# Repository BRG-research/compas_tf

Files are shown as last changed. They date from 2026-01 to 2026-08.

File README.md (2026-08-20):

# compas_tf

Timber floor development. A parametric model of a timber floor — columns, ribs,
beds, t-sections, oculus and the connectors that hold them together — that you
can build, cut, measure, extract from and hand to a shop as STEP.

**Documentation: <https://brg-research.github.io/compas_tf/>**

## Use it

```bash
pip install compas_tf
```

```python
import compas

model = compas.json_load("cantilevers_baked_model.json")

print(len(list(model.geometry_elements())))   # 237
print(len(list(model.contacts())))            # 733
```

A written model is *baked* — every boolean already evaluated and stored on the
element — so it loads in 0.60 s with no boolean backend involved.
[`compas_tf_example`](https://github.com/BRG-research/compas_tf_example) is a
standalone project that does nothing but read one.

## Develop it

Needs [git](https://git-scm.com/downloads),
[uv](https://docs.astral.sh/uv/getting-started/installation/) and Python 3.10+.

```bash
git clone https://github.com/BRG-research/compas_tf.git
cd compas_tf
uv venv .venv --python 3.12
source .venv/Scripts/activate      # macOS / Linux: source .venv/bin/activate
uv pip install -r requirements.txt -r requirements-dev.txt -r requirements-viewer.txt
uv pip install -e .
```

> `uv pip`, not plain `pip` — a `uv venv` has no pip of its own, so a bare
> `pip install` lands in the wrong environment.

```bash
invoke lint
invoke test
python tools/run_examples.py     # all 21 examples, viewer suppressed
```

## Work on another branch

A fresh clone gives you `main` and nothing else — the other branches exist on
GitHub but are not yet on your machine. `git fetch` downloads them; `git switch`
gives you a local branch that tracks one.

```bash
git fetch origin --prune         # download every branch GitHub has, drop stale ones
git branch -r                    # list what is on origin
git switch quantities            # create local `quantities` tracking origin/quantities
```

`git switch <name>` with no other flags is enough when exactly one remote has a
branch of that name — git creates the local branch and sets it to track. Spell
it out when you want a different local name, or when the shorthand fails:

```bash
git switch -c quantities --track origin/quantities
```

From then on it is an ordinary branch: `git pull` to update it, `git push` to
publish, `git switch main` to go back. `git branch -vv` shows every local branch
and which remote branch it tracks.

Two things to know before switching:

- **Commit or stash first.** `git switch` refuses to move if uncommitted changes
  would be overwritten. `git status` tells you.
- **`data/` is regenerated, not shared.** The example outputs are gitignored, so
  switching branches leaves stale JSON behind and the file dates will not match
  the branch. Re-run `python tools/run_examples.py` after switching.

The environment is per-clone, not per-branch: `.venv` and the editable install
survive a `git switch`. Redo the `uv pip install` steps only when a branch
changes `requirements*.txt` or `pyproject.toml`.

## Examples

`examples/` is a chain: each reads the JSON the one before it wrote.
`example_model_18_write_model_and_brep.py` is the hinge — it bakes the model,
finds every contact, and writes the four files the readers open:

| Example | Does |
| --- | --- |
| `example_model_19_read_model.py` | the model back — elements, tree, contacts |
| `example_model_20_read_brep.py` | the STEP — 237 closed solids |
| `example_model_21_extract_bay.py` | one column + one cantilever as its own model |
| `example_model_22_read_brep_adjacency.py` | what touches what, from STEP + sidecar |

## References

- [compas_nest](https://github.com/petrasvestartas/compas_nest) — 2D nesting of part outlines.

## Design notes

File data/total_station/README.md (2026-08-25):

# Total station 3D model

`total_station_es105` — Topcon-style ES-105 total station mounted on a survey tripod.

| file | notes |
|---|---|
| `total_station_es105.obj` | Z-up, metres, origin at the instrument's vertical axis on the ground plane. Load with `Mesh.from_obj(...)`. |
| `total_station_es105.glb` | original download (glTF binary, Y-up, textured) |
| `total_station_es105_preview.jpg` | thumbnail |

- Overall size: 1.59 × 1.55 m tripod footprint, 1.73 m to the top of the instrument.
- Triangles: 25 739 (welds to 19 164 faces when read as a COMPAS `Mesh`).

## Source / attribution

- "TOTAL STATION ES 105" by *dicki A.*, Trimble 3D Warehouse (2023-02-06)
- https://3dwarehouse.sketchup.com/model/5f67aafc-05d2-4c37-b238-7d4f63390c5f
- Covered by the Trimble 3D Warehouse General Model License: free to use in your own
  projects and renderings; do not resell or redistribute the model on its own.

The `.obj` was produced from the `.glb` by a stdlib glTF reader (node transforms baked,
Y-up rotated to Z-up); no geometry was otherwise modified apart from the origin shift.

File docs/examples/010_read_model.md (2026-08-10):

# Read the model

`compas.json_load` gives back the whole thing: elements, features, materials,
the tree, and the graph with the contacts on it.

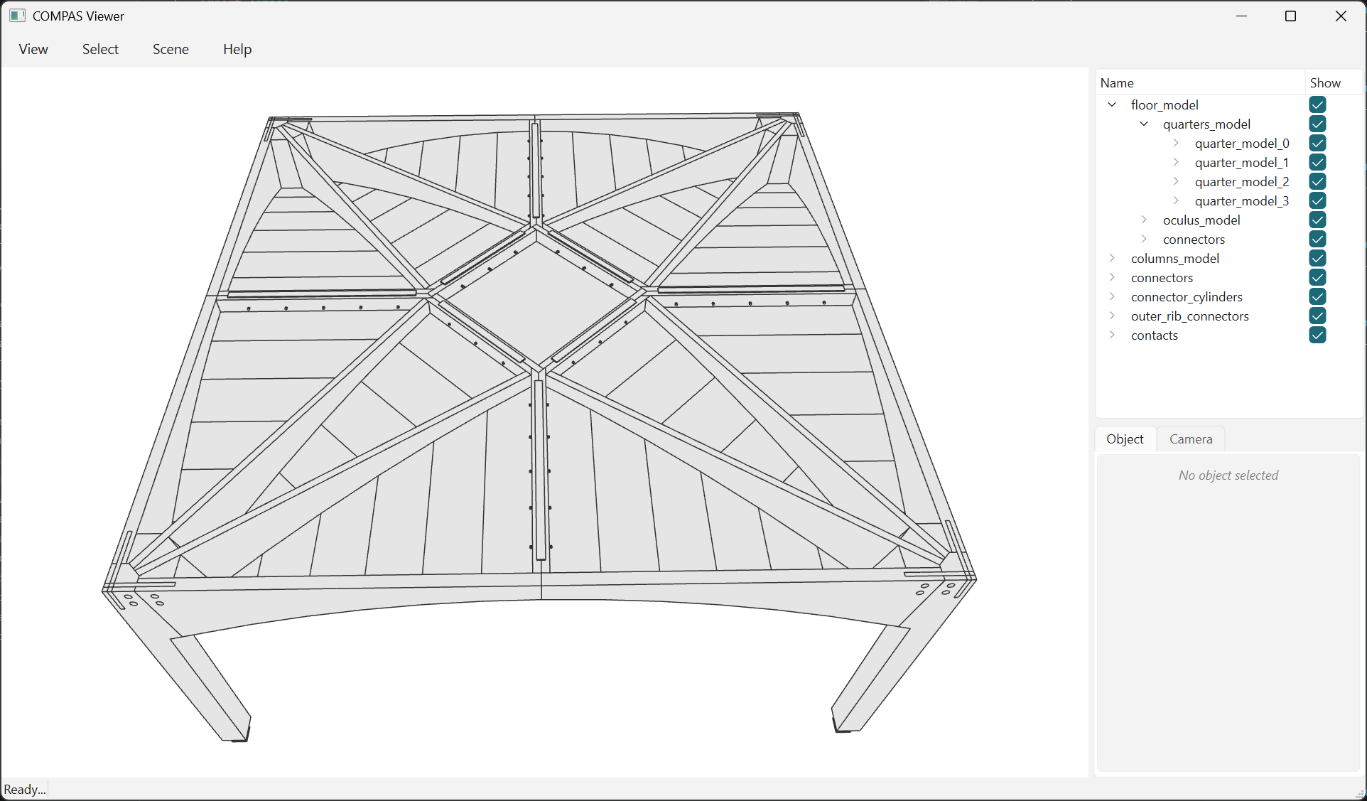
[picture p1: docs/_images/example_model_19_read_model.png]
The model loaded from JSON, with its group tree in the viewer

/// caption
237 elements, 733 contacts. The scene tree on the right is the model's own tree,
mirrored, so every group can be switched off on its own.
///

```python
--8<-- "examples/example_model_19_read_model.py"
```

```text
237 elements, 733 contacts
```

The geometry is **baked** - every boolean already evaluated and stored - so this
runs none and needs no boolean backend: 0.60 s for 3.9 MB.

What the 237 are:

```text
floor_model              185    quarters_model 136 = 4 x 34
                                oculus_model     9
                                connectors      40
columns_model              8    4 x (column + support)
connectors                 8
connector_cylinders       32
outer_rib_connectors       4
```

A quarter is 34: 18 beds, 6 t-sections, 2 outer ribs, 2 inner ribs, 3 inner
beams, 3 wedges. 145 of the 237 are `PlateElement`; the rest are the columns,
their supports, and the fasteners.

`model.elements()` yields the groups too, `geometry_elements()` only the leaves.
`model.contacts()` reads what the search stored rather than searching again.

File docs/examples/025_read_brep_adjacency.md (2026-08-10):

# Read the Breps with their adjacency

The page before draws the STEP files. This one asks them what is connected to
what, which needs the third file: the JSON sidecar.

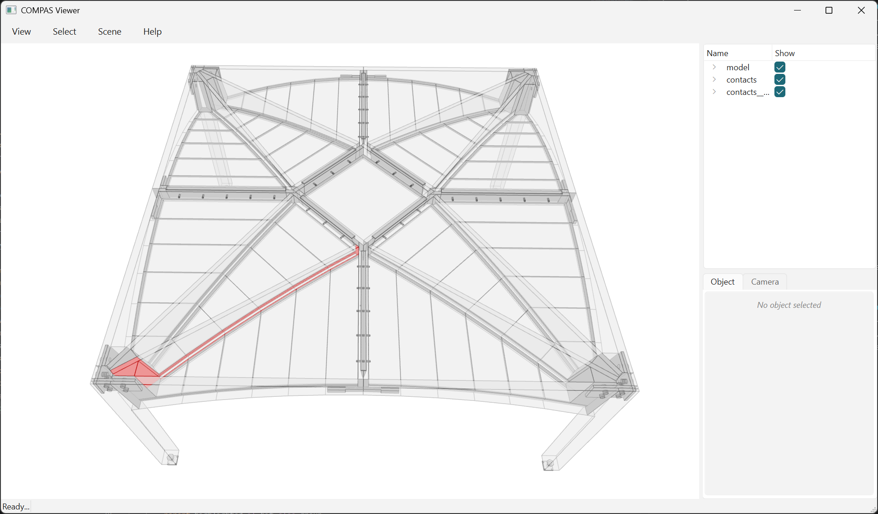
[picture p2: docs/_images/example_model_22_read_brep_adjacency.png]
One element's joints highlighted in red across the ghosted building

/// caption
The 17 contacts on `inner_ribs_0_0` in red, the rest ghosted behind them. The
sidecar is what turns "face 412" into "this rib meets that bed".
///

```python
--8<-- "examples/example_model_22_read_brep_adjacency.py"
```

```text
237 solids, 733 contact faces, 733 adjacency records
169 elements over 585 pairs, 20.92 m2 of interface

biggest joints:
   0.344 m2  inner_beams_0_1 - connector_wedge_3  (3 faces)
   0.344 m2  inner_beams_2_2 - connector_wedge_3  (3 faces)
   0.344 m2  inner_beams_0_0 - connector_wedge_0  (3 faces)
   0.344 m2  inner_beams_2_1 - connector_wedge_0  (3 faces)
   0.344 m2  inner_beams_0_2 - connector_wedge_5  (3 faces)

by type:
  12.818 m2  PlateElement - PlateElement
   4.459 m2  ConnectorWedgeElement - PlateElement
   1.106 m2  ColumnElement - PlateElement
   1.101 m2  ConnectorElement - PlateElement
   0.895 m2  ColumnElement - ConnectorElement
   0.541 m2  OuterRibConnectorElement - PlateElement

17 contacts on inner_ribs_0_0, the most connected element
```

A record per face, in the same order the faces were written:

```python
{"index": 0, "a": "beds_0_0_0", "b": "wedges_inner_beams_0_0",
 "a_type": "PlateElement", "b_type": "PlateElement",
 "a_guid": "c46c8acc-...", "b_guid": "3098146e-...",
 "area": 39851.67}
```

Three things worth knowing:

**Index is the only join.** Equal counts is the one check that the two files
came from the same run - pair a STEP with the wrong sidecar and every name lands
on the wrong face, silently.

**The names are element names.** The solids stay anonymous; nothing here says
which of the 237 is `beds_0_0_0`. For that, read the JSON model.

**A pair is not a face.** 585 pairs carry 733 faces, so group by `(a, b)` before
ranking or one joint split in three sorts below a single big one.

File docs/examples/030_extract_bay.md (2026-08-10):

# Extract one column and one cantilever

Any named group can be lifted out as a model of its own. One column plus the
cantilever it carries is the unit that gets assembled on site.

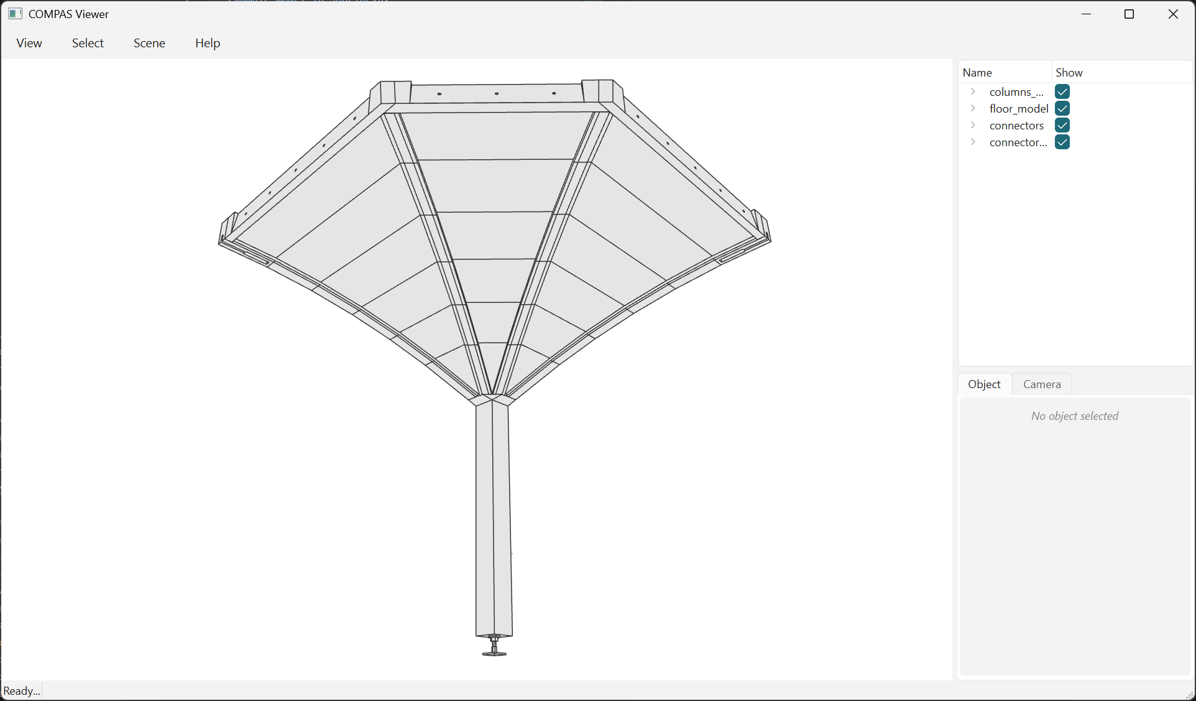
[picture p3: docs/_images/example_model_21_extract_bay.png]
One bay lifted out of the building: a column carrying one quarter

/// caption
The 46 elements that make a bay, and nothing else - cut off along the seams
where the next quarters would begin.
///

```python
--8<-- "examples/example_model_21_extract_bay.py"
```

```text
bay_0: 46 of 237 elements, 143 of 733 contacts
    34 of  145  PlateElement
     8 of   32  DowelCylinderElement
     2 of    8  ConnectorElement
     1 of    4  SupportElement
     1 of    4  ColumnElement
columns_model  (2 parts)
  column_model_0  (2 parts)
floor_model  (34 parts)
  quarters_model  (34 parts)
    quarter_model_0  (34 parts)
      beds_0  (18 parts)
        beds_0_0  (6 parts)
        beds_1_0  (6 parts)
        beds_2_0  (6 parts)
      tsections_0  (6 parts)
      outer_ribs_0  (2 parts)
      inner_ribs_0  (2 parts)
      wedges_inner_beams_0  (3 parts)
      inner_beams_0  (3 parts)
connectors  (2 parts)
connector_cylinders  (8 parts)
```

Every group keeps its place, so the bay is the same tree pruned to what it
contains, not a bag of parts. The copy is independent - fresh guids - and writes
to JSON or STEP like any other model.

**Both groups in one call.** The contacts *between* the column and its
cantilever survive only if the two come out together; extracting each on its own
and merging drops exactly that joint.

**`neighbors=` takes types, not `True`.** The fasteners live in top-level groups
holding all four bays' hardware, so they cannot be named - `neighbors=` finds
this bay's own, by contact for the connectors and by bounding box for the dowels,
which the contact search skipped and which therefore have no graph edge.

```text
neighbors=False        36 elements, 125 contacts
neighbors=FASTENERS    46 elements, 143 contacts
neighbors=True         77 elements, 208 contacts
```

`True` admits anything that touches: four plates from the quarters next door,
two oculus plates, and then `connector_wedge_7`'s cylinders, whose boxes overlap
one of those oculus plates. Naming the types stops that at the first step.

The groups you can name:

```text
floor_model                    185 parts
  quarters_model               136
    quarter_model_0 .. _3       34 each
      beds_0, tsections_0, outer_ribs_0, inner_ribs_0,
      wedges_inner_beams_0, inner_beams_0
  oculus_model                   9
  connectors                    40
columns_model                    8
  column_model_0 .. _3           2 each
connectors                       8
connector_cylinders             32
outer_rib_connectors             4
```

A name that matches nothing raises `ModelElementNotFound`.

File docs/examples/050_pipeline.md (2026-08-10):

# The full pipeline

The other pages read a finished model. This is where it comes from: a chain of
examples, each reading the JSON the one before it wrote.

```bash
python tools/run_examples.py            # all of them
python tools/run_examples.py 8 9 10     # only those, by number
```

The runner suppresses the viewer window but still builds the scene, so broken
geometry still raises, and it rewrites everything in `data/`.

| Example | Reads | Writes |
| --- | --- | --- |
| `1_floorguide` | the parameters | `floorguide.json` |
| `2_column_model` | `floorguide` | `column_model.json` |
| `3_columns_model` | `floorguide`, `column_model` | `columns_model.json` |
| `4_quarters` | `floorguide` | `quarter_model`, `quarters_model` |
| `5_oculus` | `floorguide` | `oculus_model.json` |
| `6_contacts_floor` | `quarters_model`, `oculus_model` | `floor_model.json` |
| `7_contacts_cantilever` | `quarter_model`, `column_model` | `cantilever_model.json` |
| `8_contacts_cantilevers` | `floor_model`, `columns_model` | `cantilevers_model.json` |
| `9_wedge_connector` | - | the wedge connector on its own |
| `10_shoring` | `floorguide` | `shoring_model.json` |
| `11_full` | `cantilever_model`, `shoring_model` | `full_model.json` |
| `12`, `13`, `14`, `16` | `cantilevers_model` | the parts laid out flat for fabrication |

Step 8 is the whole building: 237 elements, four quarters on four columns,
everything cut and bolted.

`18_write_model_and_brep` is the hinge. It bakes that model - every boolean
evaluated once and stored - searches every element pair for contacts on the Brep
faces, and writes the four files the reading pages open:

```text
cantilevers_baked_model.json      3.9 MB
cantilevers_baked_model.stp      19.5 MB
cantilevers_baked_contacts.stp    4.7 MB
cantilevers_baked_contacts.json   201 KB
```

It is the only step that runs a boolean, and the only one that needs a boolean
backend. Everything downstream just opens files.

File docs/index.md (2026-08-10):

# compas_tf

`compas_tf` builds the timber floor as a parametric model - columns, ribs, beds,
t-sections, the oculus and the connectors - every element boolean-cut and
contact-checked. The finished model is written as JSON and as STEP.

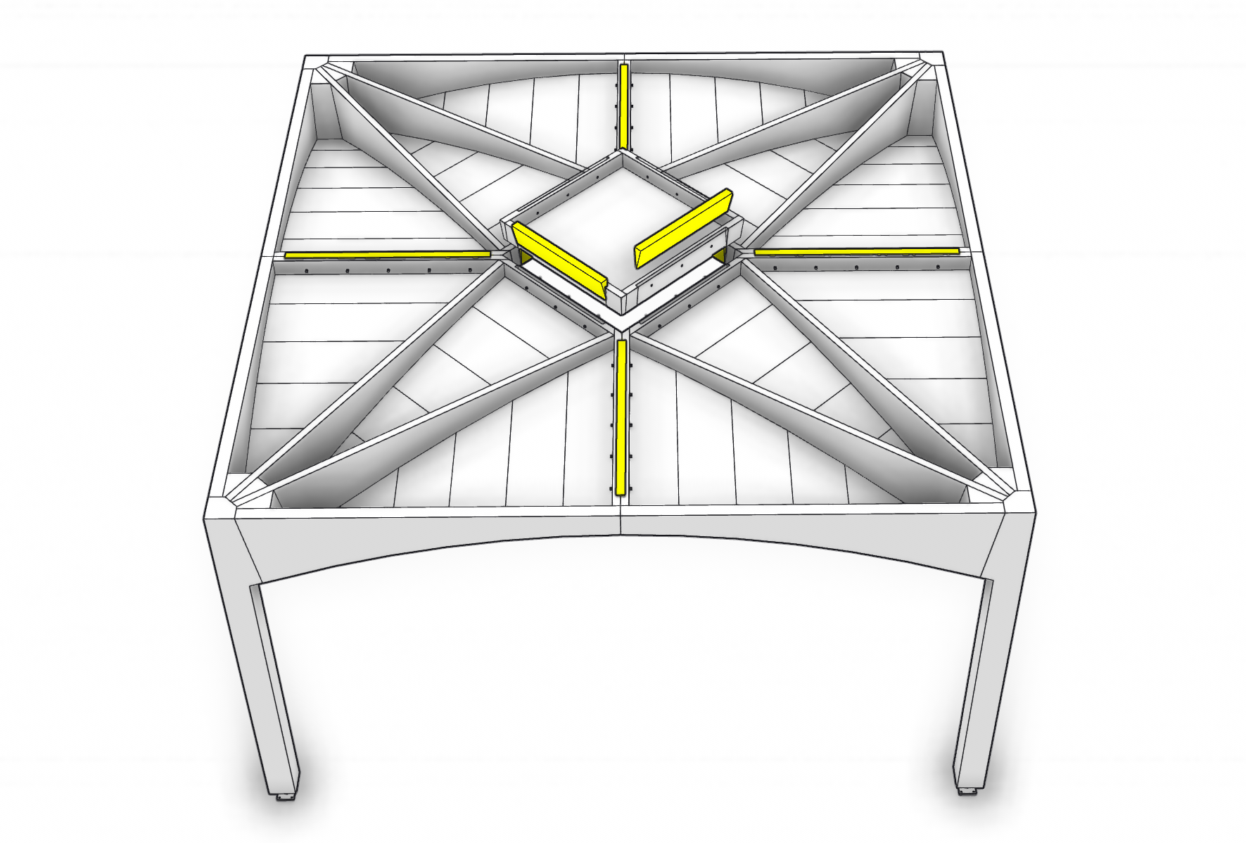
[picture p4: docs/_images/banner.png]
One bay of the timber floor

/// caption
One bay: four quarters of ribs, beds and t-sections on a column, an oculus at
the centre, and the connectors in yellow.
///

[**The presentation**](https://docs.google.com/presentation/d/1b6M9fYuQjmKMM1xWZPiqj3Y3arJCszfi/edit?slide=id.p1#slide=id.p1)
- the whole project.

[**The model as STEP**](https://github.com/BRG-research/compas_tf/raw/main/data/cantilevers_baked_model.stp)
- when geometry preview is only needed. Also as
[JSON](https://github.com/BRG-research/compas_tf/raw/main/data/cantilevers_baked_model.json),
which keeps the names, the tree and the contacts.

Reading a finished model needs nothing but `compas_tf` - start with the
[examples](examples/010_read_model.md).

Built on [compas](https://compas.dev),
[compas_model](https://github.com/blockresearchgroup/compas_model),
[compas_occt](https://github.com/petrasvestartas/compas_occt),
[compas_manifold](https://github.com/petrasvestartas/compas_manifold) and
[shapely](https://shapely.readthedocs.io), with
[compas_viewer](https://github.com/compas-dev/compas_viewer) for the pictures.

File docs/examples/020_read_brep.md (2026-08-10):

# Read the Breps

The STEP file is the same geometry with no compas_tf concepts in it: solids, the
way a shop gets them.

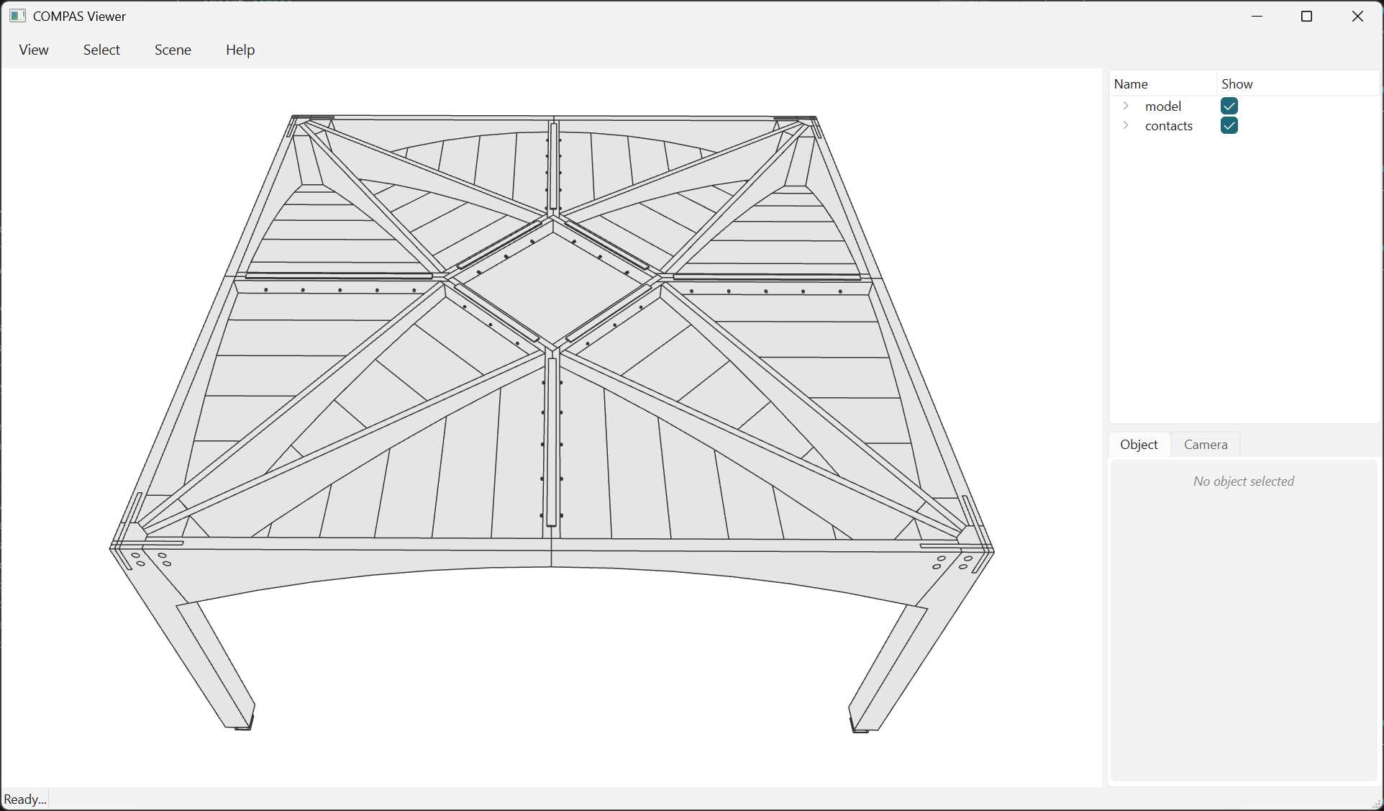
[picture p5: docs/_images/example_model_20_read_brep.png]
The same building read back from STEP

/// caption
237 solids, 19.5 MB, no compas_tf needed to open it. Compare the scene tree with
the page before: two flat entries. STEP carries no names and no hierarchy, so
there is nothing to mirror.
///

```python
--8<-- "examples/example_model_20_read_brep.py"
```

```text
237 solids, 4779 faces, 733 contacts
```

The model is one compound, so `.solids` splits out the parts. The contacts are a
second file: they are loose faces, which `.solids` would drop. Coplanar faces
were merged before writing, so 13730 mesh faces come back as 4779 Brep faces,
each drilled face carrying its hole loops.

**Set the deflection.** At the `0.001` default the building tessellates to 2.93M
triangles in 67 s; at `1.0` it is 19.8k in 2.0 s, same picture.

**STEP drops names.** Every face reads back unnamed, so this page can draw the
contacts but not say what they join. Order survives, and the sidecar uses it -
see [the next page](025_read_brep_adjacency.md).

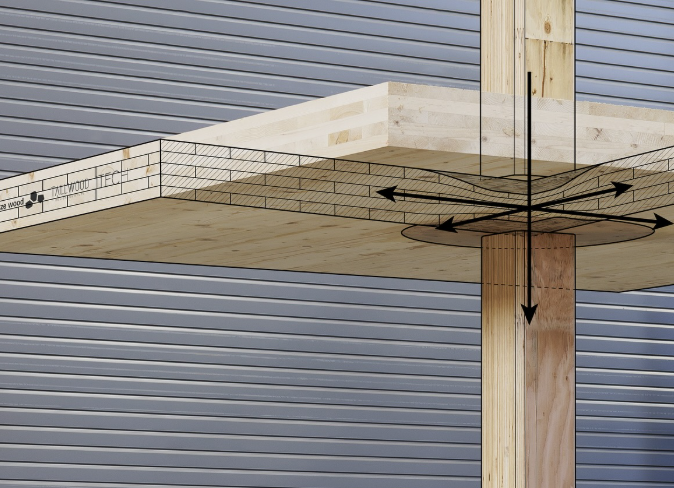
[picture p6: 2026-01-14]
docs/_images/icd_column_head_clt.png

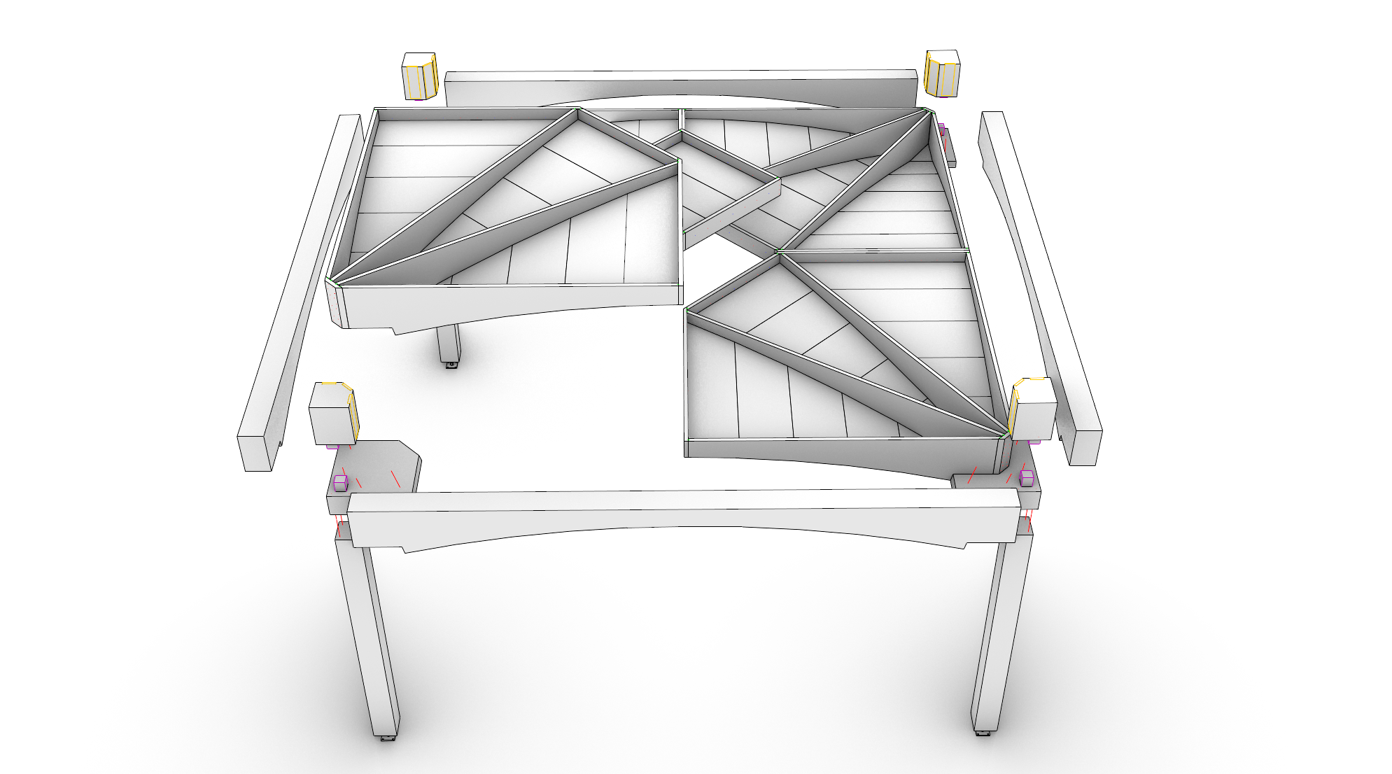
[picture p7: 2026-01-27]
docs/_images/model4.png

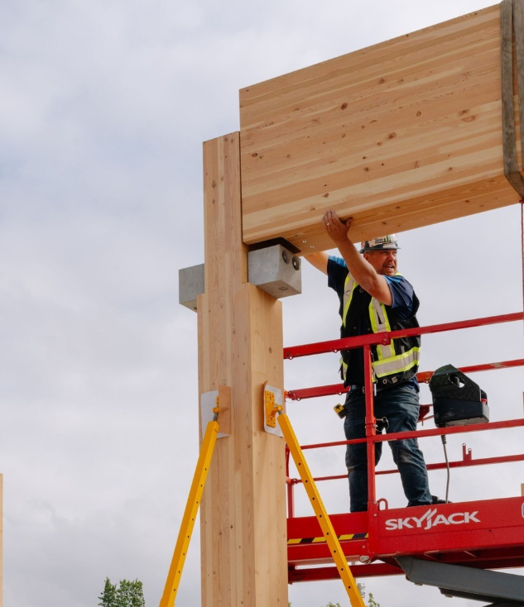
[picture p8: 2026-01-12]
docs/references/fastepp2.png

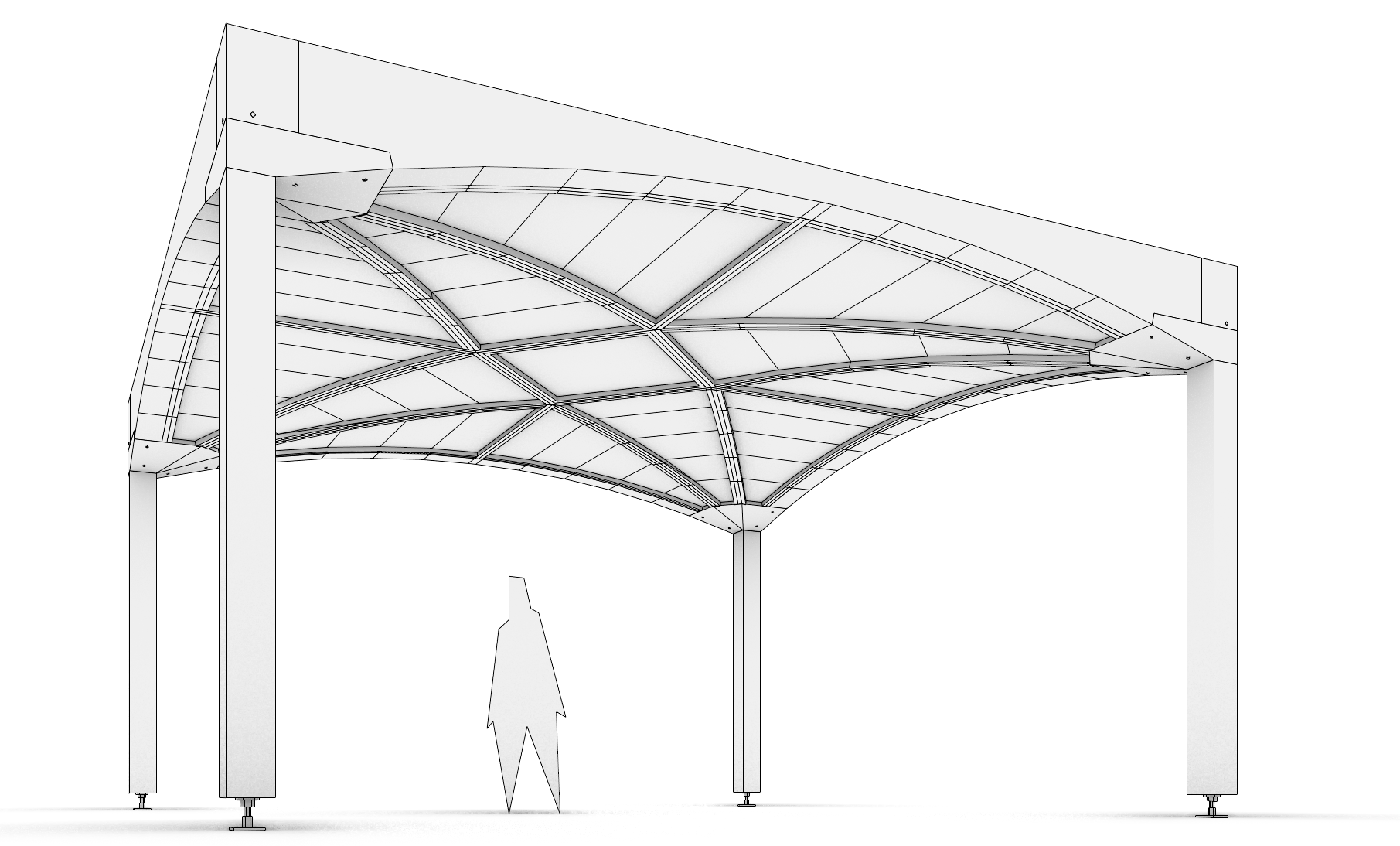
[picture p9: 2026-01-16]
docs/_images/screenshot_4.png

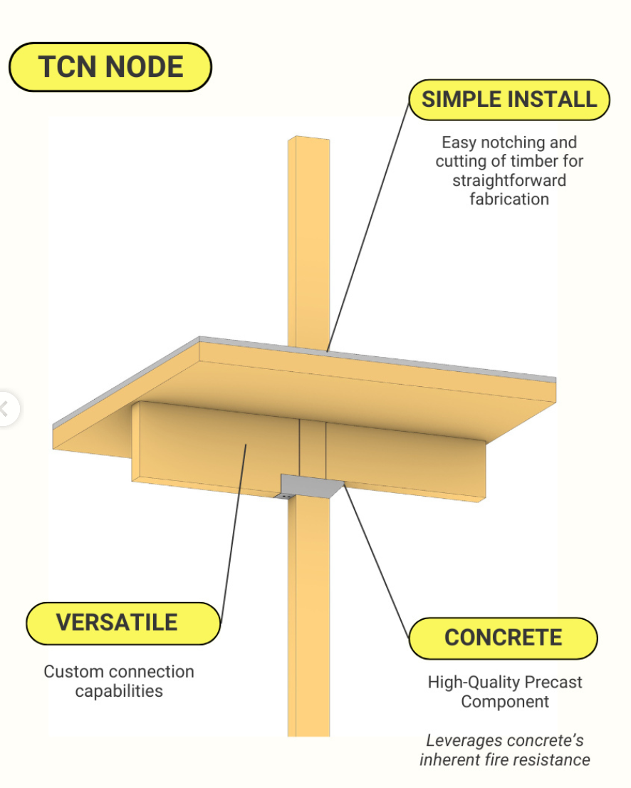
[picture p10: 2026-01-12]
docs/references/fastepp.png

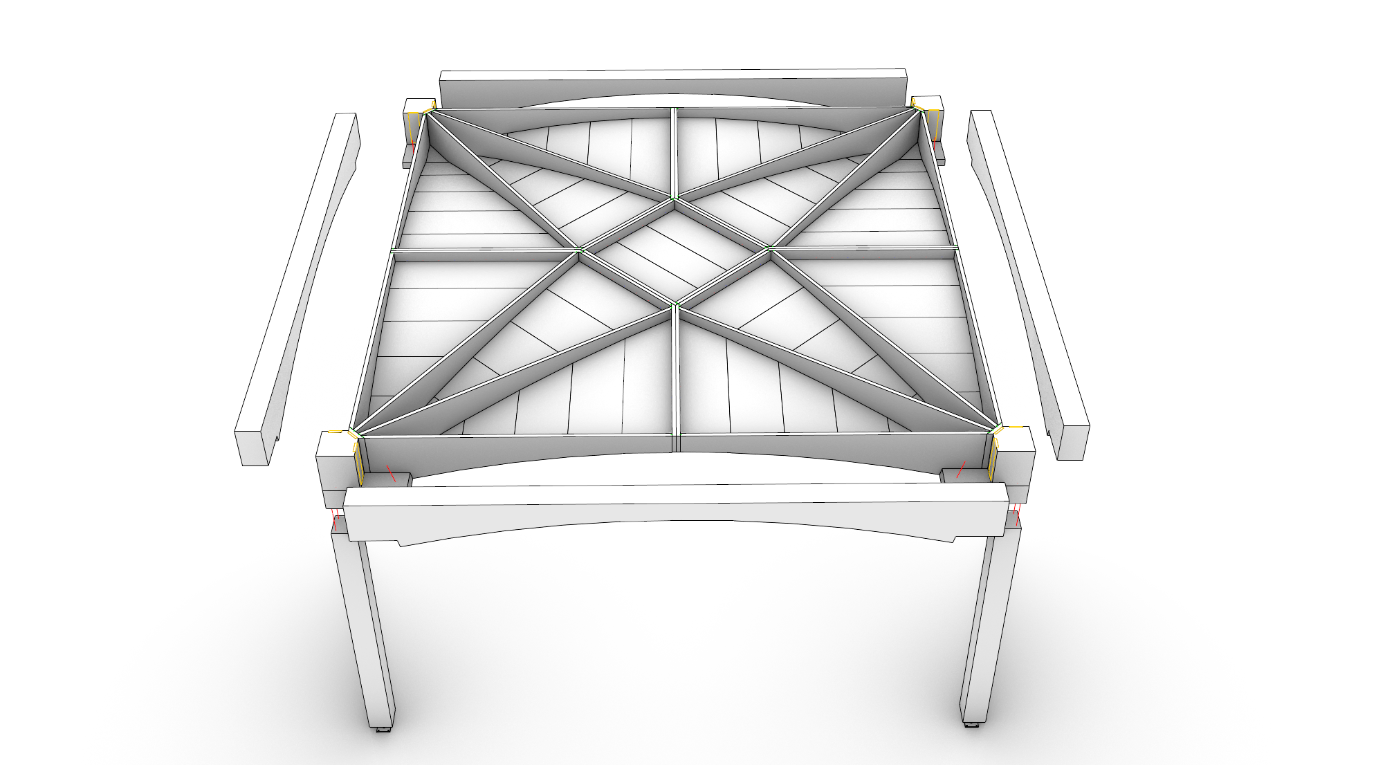
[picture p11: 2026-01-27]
docs/_images/model3.png

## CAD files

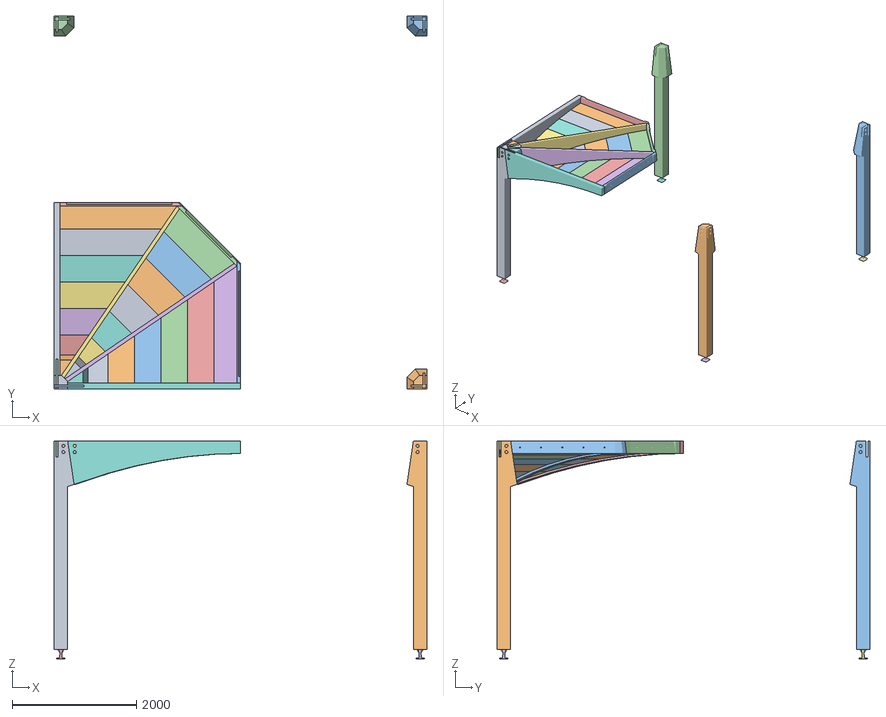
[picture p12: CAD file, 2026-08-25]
data/assembly/assembly_step6_preview.obj
6000.0 x 6000.0 x 3500.0
column_0
column_1
column_2
column_3
support_0
support_1
support_2
support_3
beds_0_0_0
beds_0_1_0
beds_0_2_0
beds_0_3_0
beds_0_4_0
beds_0_5_0
beds_1_0_0
beds_1_1_0
beds_1_2_0
beds_1_3_0
beds_1_4_0
beds_1_5_0
beds_2_0_0
beds_2_1_0
beds_2_2_0
beds_2_3_0
beds_2_4_0
beds_2_5_0
inner_beams_0_0
inner_beams_1_0
inner_beams_2_0
inner_ribs_0_0
inner_ribs_1_0
outer_ribs_0_0
outer_ribs_1_0
tsections_0_0
tsections_1_0
tsections_2_0
tsections_3_0
tsections_4_0
tsections_5_0
wedges_inner_beams_0_0
wedges_inner_beams_1_0
wedges_inner_beams_2_0
connector_0
connector_1
connector_0_cylinder_column_0
connector_0_cylinder_column_1
connector_0_cylinder_rib_0
connector_0_cylinder_rib_1
connector_1_cylinder_column_0
connector_1_cylinder_column_1
connector_1_cylinder_rib_0
connector_1_cylinder_rib_1

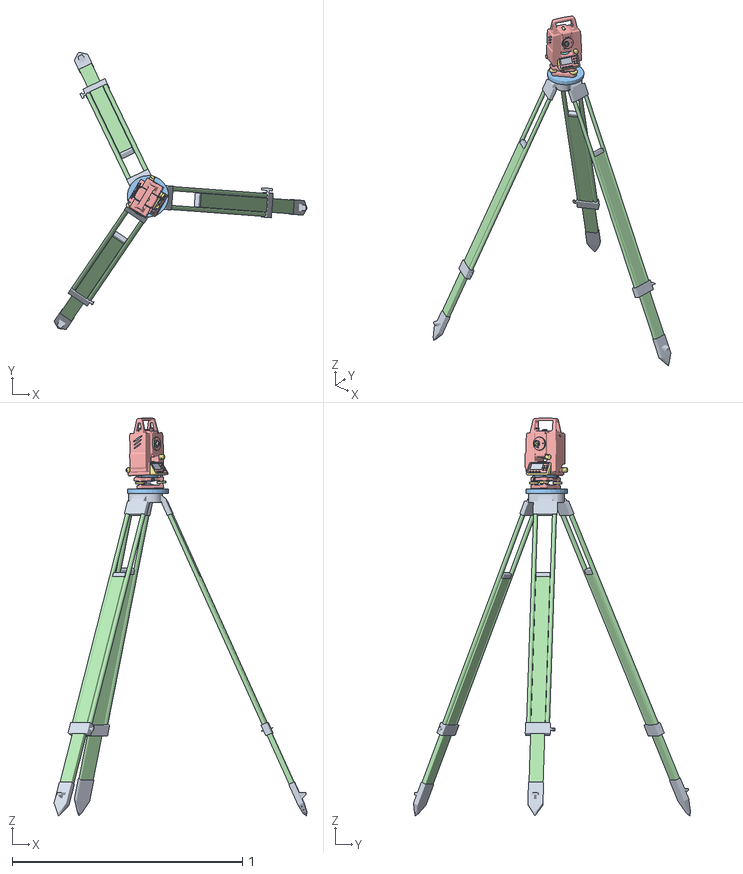
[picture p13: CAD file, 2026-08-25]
data/total_station/total_station_es105.obj
1.10 x 1.20 x 1.73

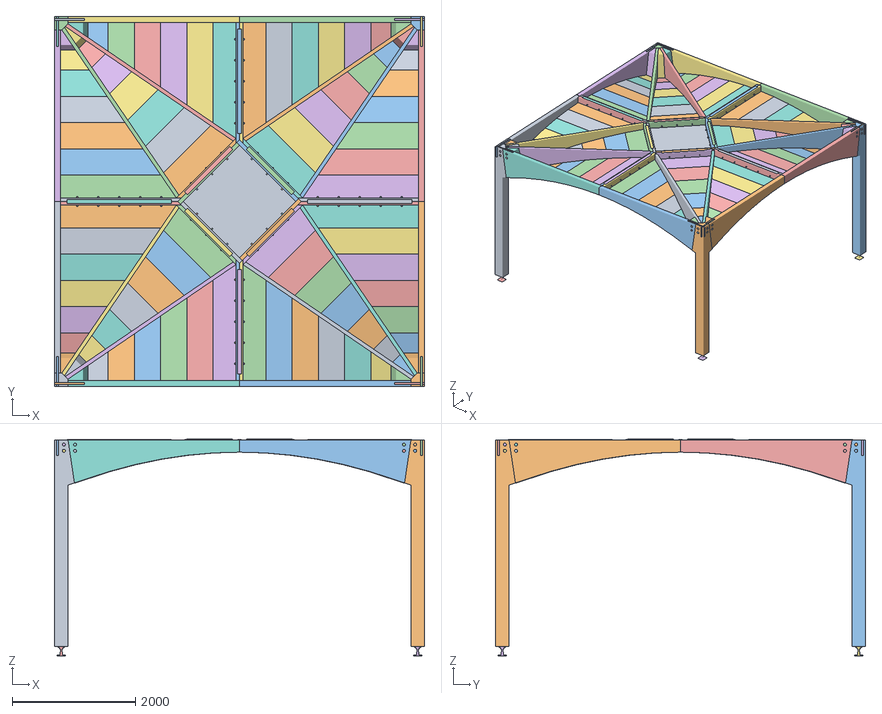
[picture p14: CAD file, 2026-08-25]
data/assembly/assembly_step9_preview.obj
6000.0 x 6000.0 x 3514.3
column_0
column_1
column_2
column_3
support_0
support_1
support_2
support_3
beds_0_0_0
beds_0_1_0
beds_0_2_0
beds_0_3_0
beds_0_4_0
beds_0_5_0
beds_1_0_0
beds_1_1_0
beds_1_2_0
beds_1_3_0
beds_1_4_0
beds_1_5_0
beds_2_0_0
beds_2_1_0
beds_2_2_0
beds_2_3_0
beds_2_4_0
beds_2_5_0
inner_beams_0_0
inner_beams_1_0
inner_beams_2_0
inner_ribs_0_0
inner_ribs_1_0
outer_ribs_0_0
outer_ribs_1_0
tsections_0_0
tsections_1_0
tsections_2_0
tsections_3_0
tsections_4_0
tsections_5_0
wedges_inner_beams_0_0
wedges_inner_beams_1_0
wedges_inner_beams_2_0
beds_0_0_1
beds_0_1_1
beds_0_2_1
beds_0_3_1
beds_0_4_1
beds_0_5_1
beds_1_0_1
beds_1_1_1
beds_1_2_1
beds_1_3_1
beds_1_4_1
beds_1_5_1
beds_2_0_1
beds_2_1_1
beds_2_2_1
beds_2_3_1
beds_2_4_1
beds_2_5_1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

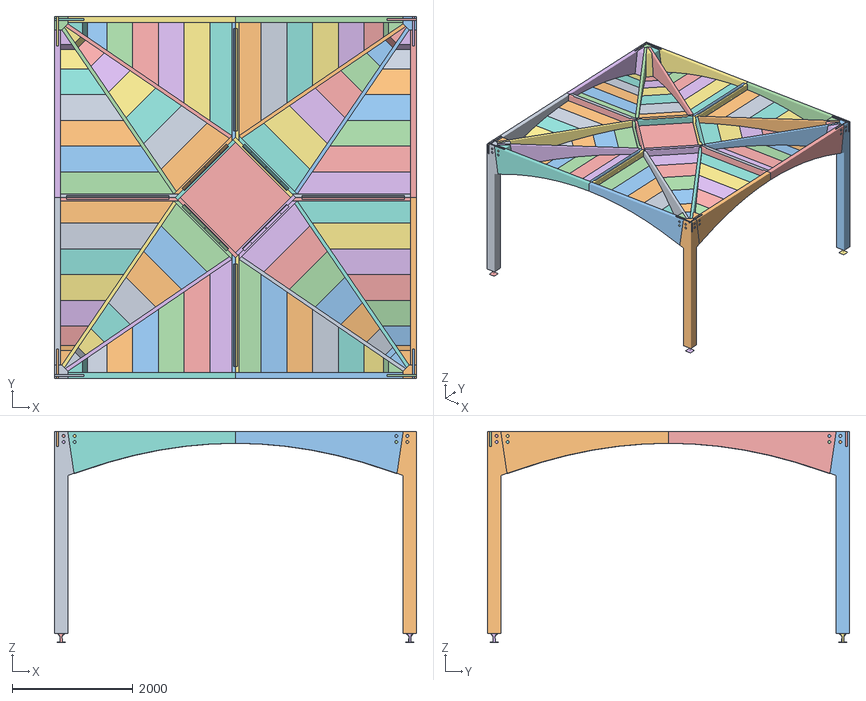
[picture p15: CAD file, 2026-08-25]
data/assembly/assembly_step8_preview.obj
6000.0 x 6000.0 x 3500.0
column_0
column_1
column_2
column_3
support_0
support_1
support_2
support_3
beds_0_0_0
beds_0_1_0
beds_0_2_0
beds_0_3_0
beds_0_4_0
beds_0_5_0
beds_1_0_0
beds_1_1_0
beds_1_2_0
beds_1_3_0
beds_1_4_0
beds_1_5_0
beds_2_0_0
beds_2_1_0
beds_2_2_0
beds_2_3_0
beds_2_4_0
beds_2_5_0
inner_beams_0_0
inner_beams_1_0
inner_beams_2_0
inner_ribs_0_0
inner_ribs_1_0
outer_ribs_0_0
outer_ribs_1_0
tsections_0_0
tsections_1_0
tsections_2_0
tsections_3_0
tsections_4_0
tsections_5_0
wedges_inner_beams_0_0
wedges_inner_beams_1_0
wedges_inner_beams_2_0
beds_0_0_1
beds_0_1_1
beds_0_2_1
beds_0_3_1
beds_0_4_1
beds_0_5_1
beds_1_0_1
beds_1_1_1
beds_1_2_1
beds_1_3_1
beds_1_4_1
beds_1_5_1
beds_2_0_1
beds_2_1_1
beds_2_2_1
beds_2_3_1
beds_2_4_1
beds_2_5_1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

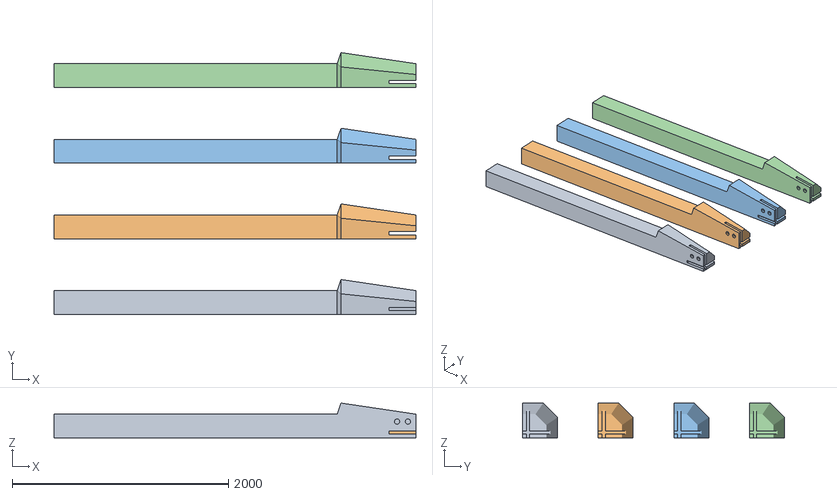
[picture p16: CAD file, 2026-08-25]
data/assembly/assembly_step3_preview.obj
3350.0 x 2423.0 x 323.0
column_0
column_1
column_2
column_3
support_0_head_plate
support_1_head_plate
support_2_head_plate
support_3_head_plate
support_0_screw_0
support_0_screw_1
support_0_screw_2
support_1_screw_0
support_1_screw_1
support_1_screw_2
support_2_screw_0
support_2_screw_1
support_2_screw_2
support_3_screw_0
support_3_screw_1
support_3_screw_2

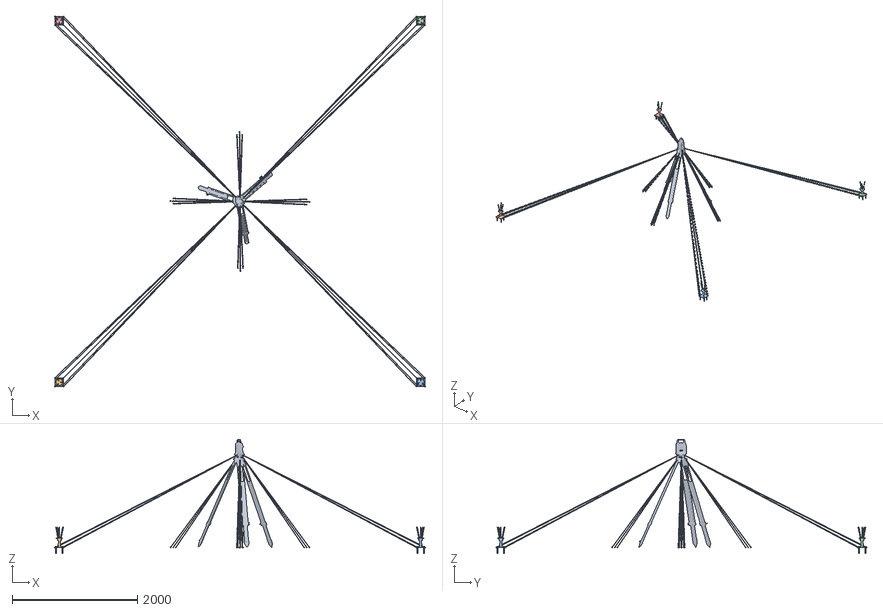
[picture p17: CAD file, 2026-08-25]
data/assembly/assembly_step2_preview.obj
5935.8 x 5935.8 x 1827.4
total_station_es105
support_0
support_1
support_2
support_3
support_0_fastener_0
support_0_fastener_1
support_0_fastener_2
support_0_fastener_3
support_0_fastener_4
support_0_fastener_5
support_0_fastener_6
support_1_fastener_0
support_1_fastener_1
support_1_fastener_2
support_1_fastener_3
support_1_fastener_4
support_1_fastener_5
support_1_fastener_6
support_2_fastener_0
support_2_fastener_1
support_2_fastener_2
support_2_fastener_3
support_2_fastener_4
support_2_fastener_5
support_2_fastener_6
support_3_fastener_0
support_3_fastener_1
support_3_fastener_2
support_3_fastener_3
support_3_fastener_4
support_3_fastener_5
support_3_fastener_6
beam_0_0
beam_0_1
beam_0_2
beam_0_3
beam_1_0
beam_1_1
beam_1_2
beam_1_3
beam_2_0
beam_2_1
beam_2_2
beam_2_3
beam_3_0
beam_3_1
beam_3_2
beam_3_3
point_0_0
point_0_1
point_0_2
point_0_3
point_1_0
point_1_1
point_1_2
point_1_3
point_2_0
point_2_1
point_2_2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

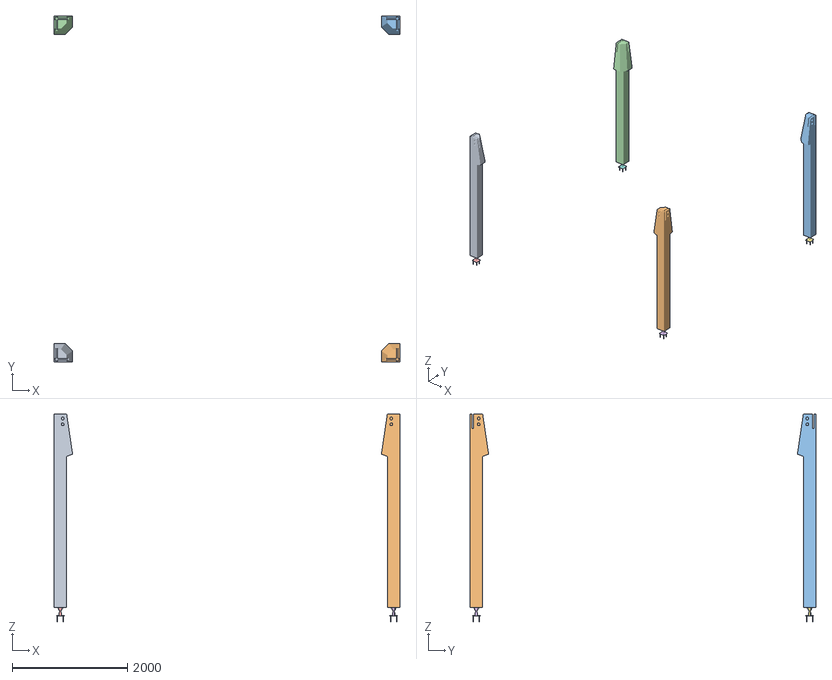
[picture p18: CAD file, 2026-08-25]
data/assembly/assembly_step4_preview.obj
6000.0 x 6000.0 x 3600.0
column_0
column_1
column_2
column_3
support_0
support_1
support_2
support_3
support_0_fastener_0
support_0_fastener_1
support_0_fastener_2
support_0_fastener_3
support_0_fastener_4
support_0_fastener_5
support_0_fastener_6
support_1_fastener_0
support_1_fastener_1
support_1_fastener_2
support_1_fastener_3
support_1_fastener_4
support_1_fastener_5
support_1_fastener_6
support_2_fastener_0
support_2_fastener_1
support_2_fastener_2
support_2_fastener_3
support_2_fastener_4
support_2_fastener_5
support_2_fastener_6
support_3_fastener_0
support_3_fastener_1
support_3_fastener_2
support_3_fastener_3
support_3_fastener_4
support_3_fastener_5
support_3_fastener_6

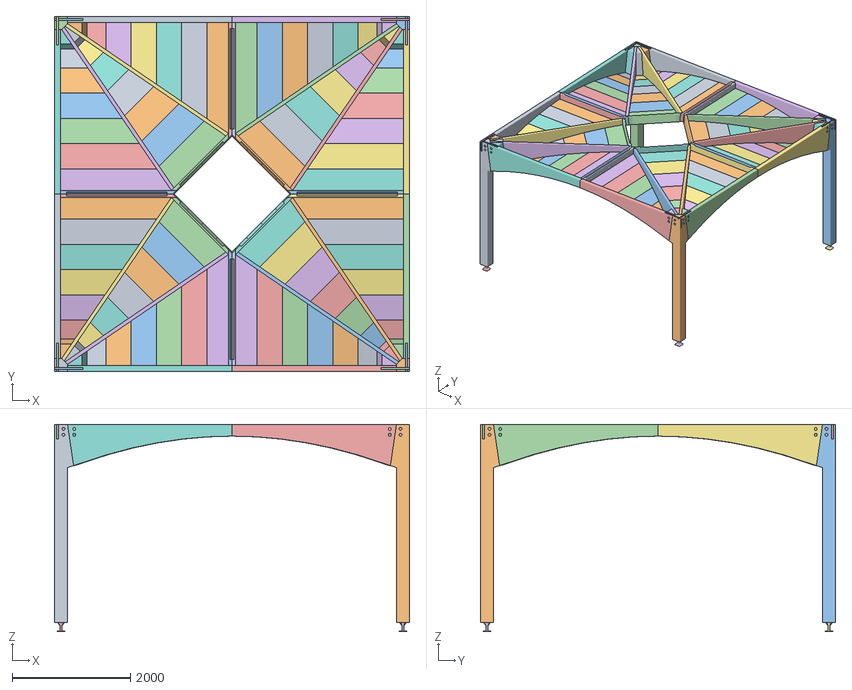
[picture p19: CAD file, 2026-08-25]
data/assembly/assembly_step7_preview.obj
6000.0 x 6000.0 x 3500.0
column_0
column_1
column_2
column_3
support_0
support_1
support_2
support_3
beds_0_0_0
beds_0_1_0
beds_0_2_0
beds_0_3_0
beds_0_4_0
beds_0_5_0
beds_1_0_0
beds_1_1_0
beds_1_2_0
beds_1_3_0
beds_1_4_0
beds_1_5_0
beds_2_0_0
beds_2_1_0
beds_2_2_0
beds_2_3_0
beds_2_4_0
beds_2_5_0
inner_beams_0_0
inner_beams_1_0
inner_beams_2_0
inner_ribs_0_0
inner_ribs_1_0
outer_ribs_0_0
outer_ribs_1_0
tsections_0_0
tsections_1_0
tsections_2_0
tsections_3_0
tsections_4_0
tsections_5_0
wedges_inner_beams_0_0
wedges_inner_beams_1_0
wedges_inner_beams_2_0
connector_0
connector_1
connector_0_cylinder_column_0
connector_0_cylinder_column_1
connector_0_cylinder_rib_0
connector_0_cylinder_rib_1
connector_1_cylinder_column_0
connector_1_cylinder_column_1
connector_1_cylinder_rib_0
connector_1_cylinder_rib_1
beds_0_0_1
beds_0_1_1
beds_0_2_1
beds_0_3_1
beds_0_4_1
beds_0_5_1
beds_1_0_1
beds_1_1_1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

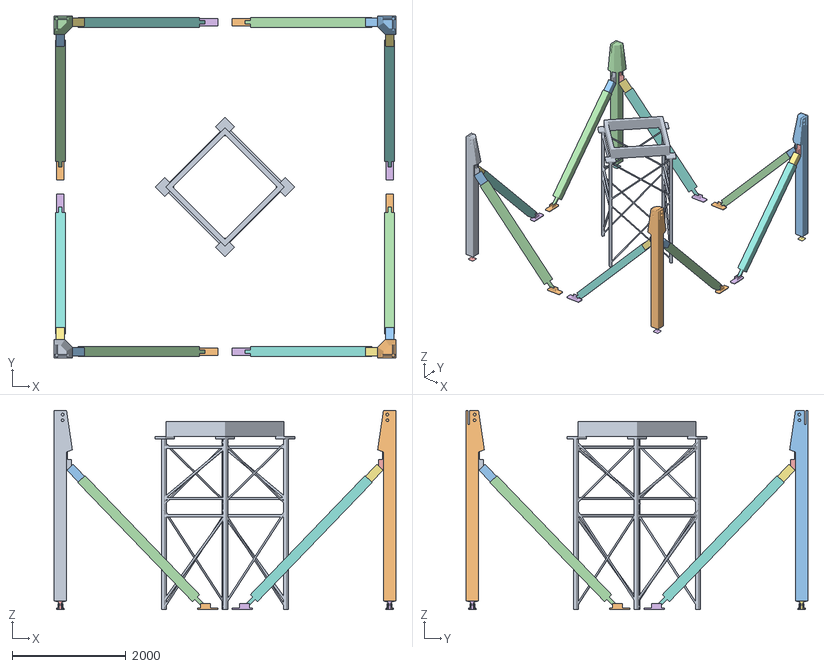
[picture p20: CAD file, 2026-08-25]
data/assembly/assembly_step5_preview.obj
6000.0 x 6000.0 x 3500.0
column_0
column_1
column_2
column_3
support_0
support_1
support_2
support_3
brace_0_schoring_foot_0
brace_0_schoring_head_0
brace_0_schoring_body_start_0
brace_0_schoring_body_end_0
brace_1_schoring_foot_0
brace_1_schoring_head_0
brace_1_schoring_body_start_0
brace_1_schoring_body_end_0
brace_2_schoring_foot_0
brace_2_schoring_head_0
brace_2_schoring_body_start_0
brace_2_schoring_body_end_0
brace_3_schoring_foot_0
brace_3_schoring_head_0
brace_3_schoring_body_start_0
brace_3_schoring_body_end_0
brace_4_schoring_foot_0
brace_4_schoring_head_0
brace_4_schoring_body_start_0
brace_4_schoring_body_end_0
brace_5_schoring_foot_0
brace_5_schoring_head_0
brace_5_schoring_body_start_0
brace_5_schoring_body_end_0
brace_6_schoring_foot_0
brace_6_schoring_head_0
brace_6_schoring_body_start_0
brace_6_schoring_body_end_0
brace_7_schoring_foot_0
brace_7_schoring_head_0
brace_7_schoring_body_start_0
brace_7_schoring_body_end_0
tower

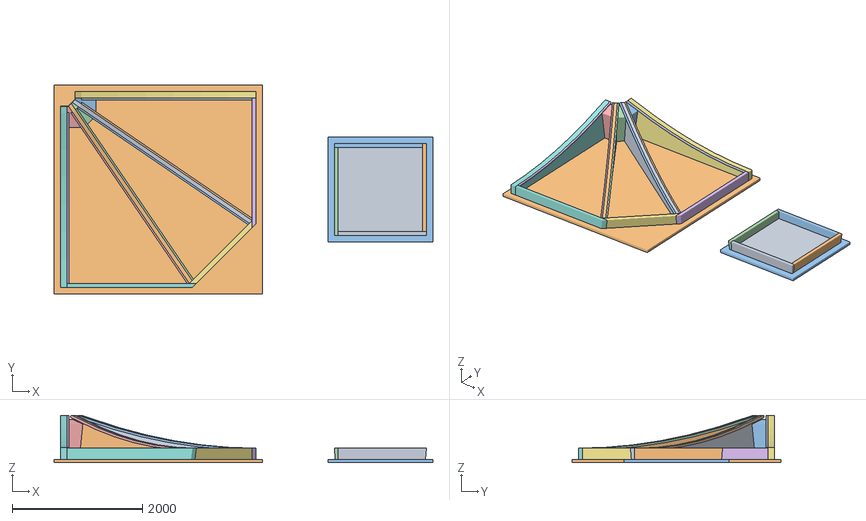
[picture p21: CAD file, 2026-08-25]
data/assembly/assembly_step1_preview.obj
5814.2 x 3200.0 x 725.9
tsections_0_0
tsections_1_0
tsections_2_0
tsections_3_0
tsections_4_0
tsections_5_0
outer_ribs_0_0
outer_ribs_1_0
inner_ribs_0_0
inner_ribs_1_0
wedges_inner_beams_0_0
wedges_inner_beams_1_0
wedges_inner_beams_2_0
inner_beams_0_0
inner_beams_1_0
inner_beams_2_0
oculus_0
oculus_1
oculus_2
oculus_3
oculus_4
oculus_5
oculus_6
oculus_7
oculus_8
jig_quarter_0
jig_oculus
outer_ribs_0_0_pocket
outer_ribs_1_0_pocket
inner_ribs_0_0_pocket
inner_ribs_1_0_pocket
wedges_inner_beams_0_0_pocket
wedges_inner_beams_1_0_pocket
wedges_inner_beams_2_0_pocket
inner_beams_0_0_pocket
inner_beams_1_0_pocket
inner_beams_2_0_pocket
oculus_0_pocket
oculus_1_pocket
oculus_2_pocket
oculus_3_pocket
oculus_4_pocket
oculus_5_pocket
oculus_6_pocket
oculus_7_pocket

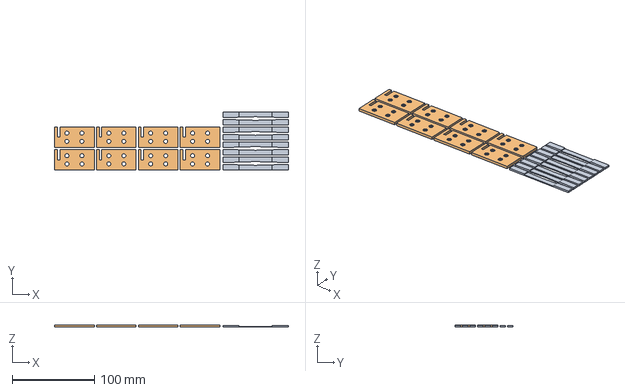
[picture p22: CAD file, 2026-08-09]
data/Custom_Cutting_Connectors/geometry.stp
284.8 x 70.8 x 3.00 mm

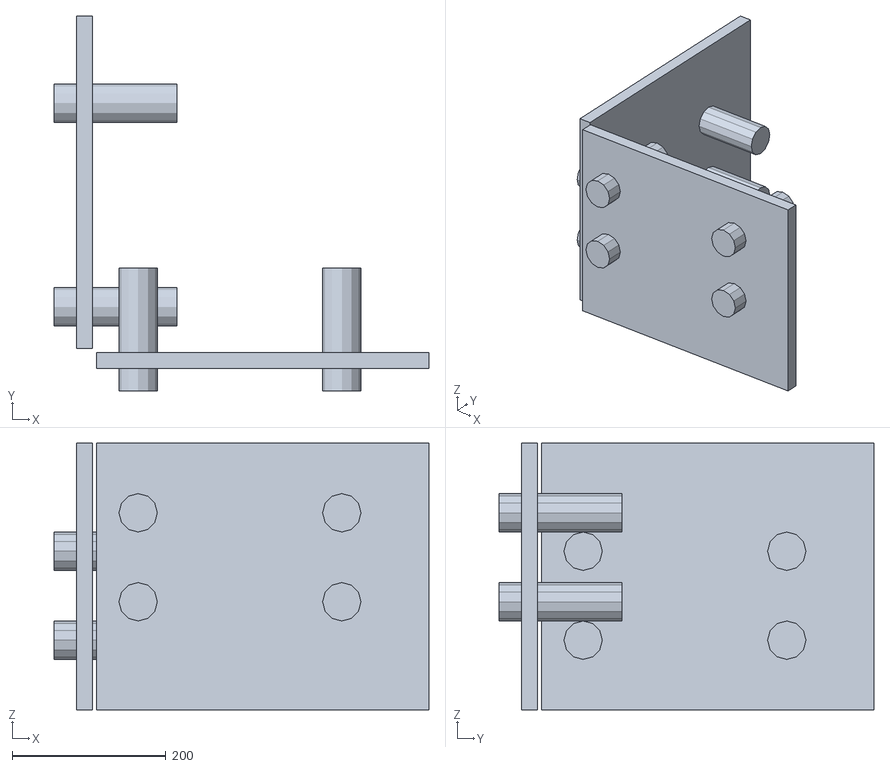
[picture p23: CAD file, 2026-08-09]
data/FloorColumnConnection/FloorColumnConnection.obj
488.0 x 488.0 x 347.3

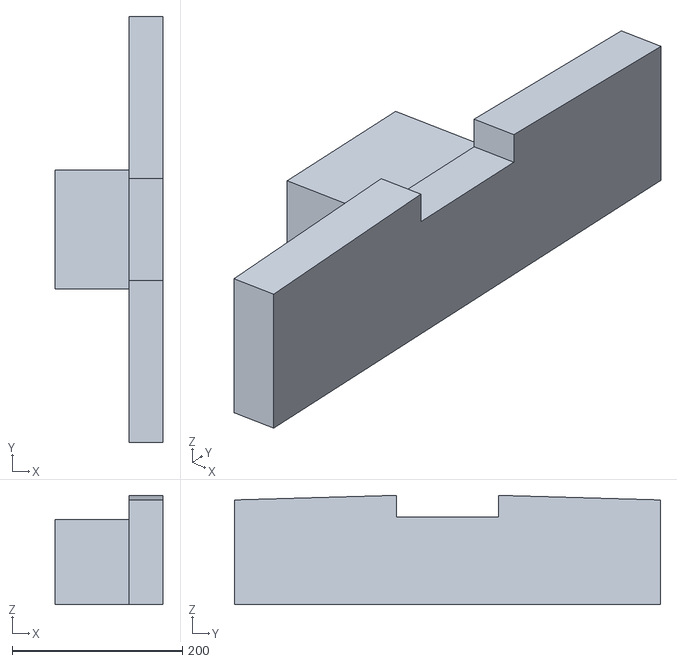
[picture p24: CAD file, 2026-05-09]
data/SchoringElement/schoring_head_custom.obj
127.0 x 500.0 x 128.3

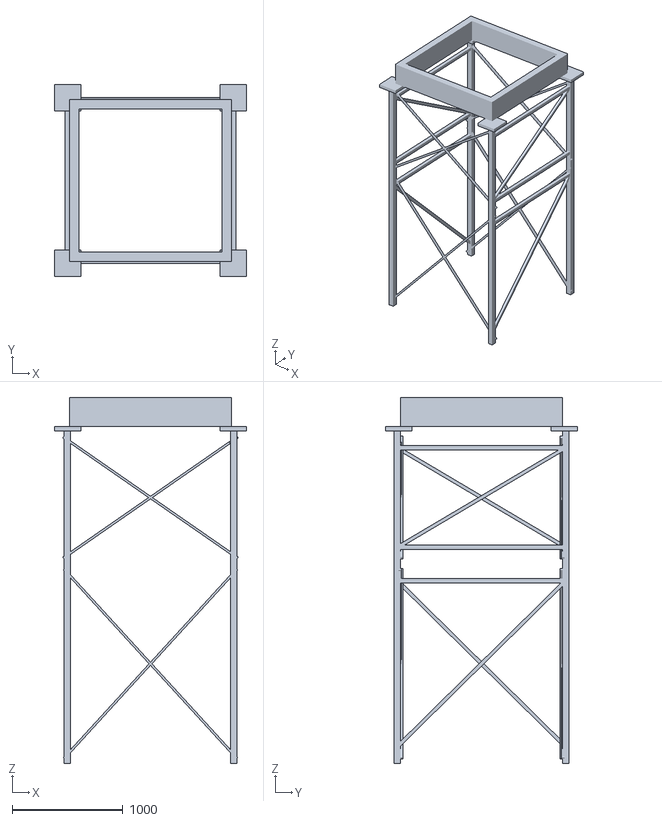
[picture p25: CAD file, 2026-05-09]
data/TowerElement/floor_tower_0.obj
1734.2 x 1734.2 x 3303.0

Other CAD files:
data/cantilevers_baked_model.stp
data/fabrication/model_0_fab.stp
src/compas_tf/data/column_base_power_base_sherpa_150402_PB_L-140-C.obj
src/compas_tf/data/OuterRibConnector/OuterRibConnector_Result.obj
data/Custom_Cutting_Connectors/Mill_6mm.obj
data/Custom_Cutting_Connectors/Ramp_2mm.obj
data/SchoringElement/custom_head0.obj
data/SchoringElement/schoring_vertical_body_end_0.obj
data/SchoringElement/schoring_vertical_body_end_1.obj
data/SchoringElement/schoring_vertical_body_end_2.obj
data/SchoringElement/schoring_vertical_body_end_3.obj
data/SchoringElement/schoring_vertical_body_end_4.obj
data/SchoringElement/schoring_vertical_body_end_5.obj
data/SchoringElement/schoring_vertical_body_start_0.obj
data/SchoringElement/schoring_vertical_body_start_1.obj
data/SchoringElement/schoring_vertical_body_start_2.obj
data/SchoringElement/schoring_vertical_body_start_3.obj
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

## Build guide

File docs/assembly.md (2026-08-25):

---
hide:
  - toc
---

# Assembly

<!-- One section per assembly step: a title, a 3D viewer, a description of what
     happens on site. No tables - the part list already carries the numbers;
     this page carries the sequence.

     Each viewer loads the coloured preview an `examples/example_model_23_assembly_*`
     script writes to `data/assembly/`, published at `_models/` by
     hooks/fabrication_assets.py. Two files are named per viewer, the OBJ and
     its MTL: Online 3D Viewer only fetches what it is handed, and without the
     MTL every part comes out the same grey. Drag to orbit, click to open the
     step full size. -->

<div class="assembly" markdown="block">

## Step 1 &mdash; Build the quarters and the oculus in a jig

<!-- The shop, before anything reaches the slab. Both pieces are solid: neither
     is context for the other. Same wide-bay wrapper as the site steps. -->

<div class="viewer-bay">
<span class="online_3d_viewer" data-model="_models/assembly_step1_preview.obj,_models/assembly_step1_preview.mtl" camera="-5800,-7000,4700,-300,-1500,200,0,0,1" edgesettings="on,0,0,0,45"></span>
</div>

<div class="side-by-side side-by-side--wide" markdown>

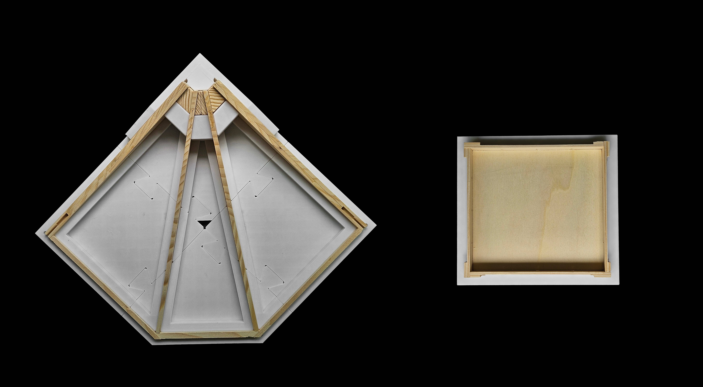
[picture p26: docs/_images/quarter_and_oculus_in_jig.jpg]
A floor quarter and an oculus element face down in their jigs


<div markdown>
Each quarter is built **upside down** in a jig, and the oculus in one of its
own beside it. The face that becomes the soffit points at the ceiling of the
shop, so the beds go on downhand, onto ribs already standing on their top edges.

**In total**

--8<-- "data/assembly/assembly_step1_points.md:totals"
</div>

</div>

## Step 2 &mdash; Set out the column bases (Sherpa Power Base 150402_PB_L-140-C)

<!-- The `camera` is not optional here: without one, Online 3D Viewer falls back
     to its own Y-up default and lays the building on its side. The last three
     numbers are the up vector - `0,0,1` for every model in this repo.

     This used to be a close-up of support_0 with the tripod behind it, from
     0.7 m out. It cannot be any more: the session now stakes out the tower legs
     in the middle as well as the four bases at the corners, so the shot has to
     hold the whole floor - station in the middle, beams reaching out to every
     mark. Same wide-bay treatment as steps 4 and 5: the `viewer-bay` wrapper
     does the zooming, the camera only sets the direction.

     Edges are ON and BLACK (`on,<r>,<g>,<b>,<threshold>`), same as step 3.
     They had to be off while the parts were meshes - every facet of the beams
     and the balls got outlined. Now the parts are Breps tessellated low-poly,
     ~13 segments round a circle, so neighbouring facets differ by ~28 degrees
     and the 45 degree threshold passes straight over them. Only real edges
     draw. The total station is the exception: it is a downloaded triangle
     mesh, so it carries more lines than the parts do. -->

<div class="viewer-bay">
<span class="online_3d_viewer" data-model="_models/assembly_step2_preview.obj,_models/assembly_step2_preview.mtl" camera="-4220,-4220,4200,0,0,600,0,0,1" edgesettings="on,0,0,0,45"></span>
</div>

<!-- The photo carries the same colour key as the viewer above it: the dots are
     absolutely positioned in per cent of the image, so they ride along with it
     at any width. Colours are the BLUE/PINK of
     examples/example_model_23_assembly_step2.py. -->

<div class="side-by-side side-by-side--wide" markdown>

<div class="marked-photo" markdown>
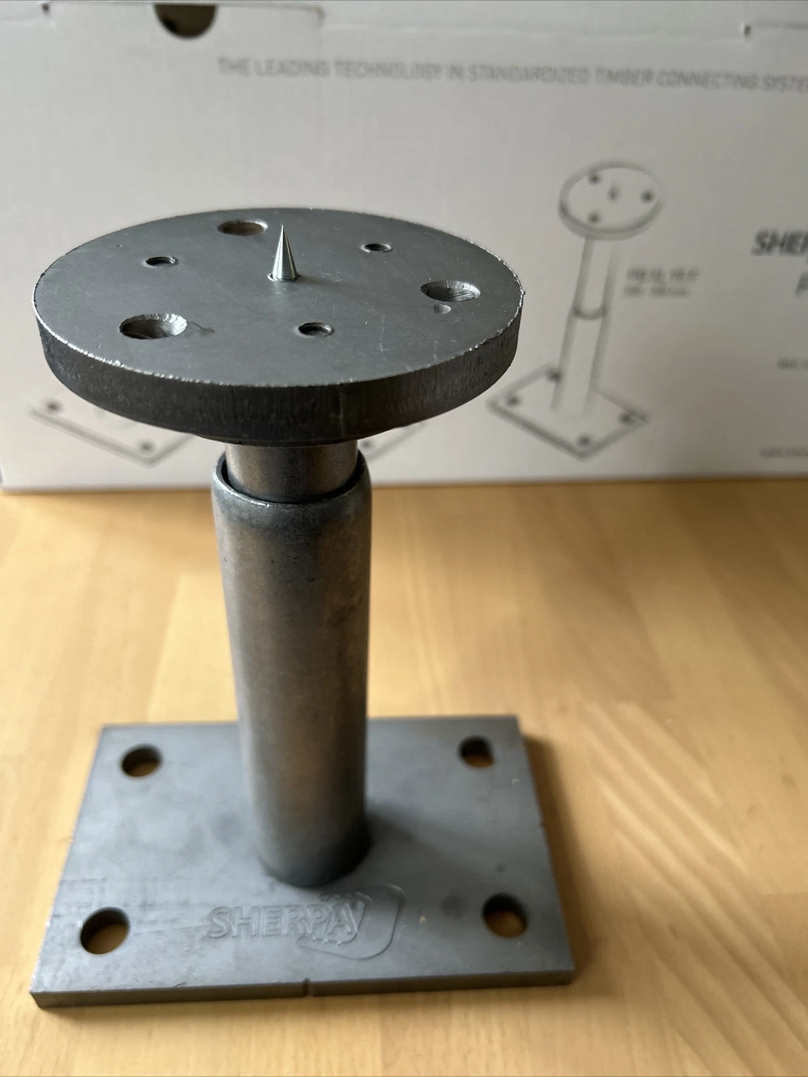
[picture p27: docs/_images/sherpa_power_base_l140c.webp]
SHERPA Power Base L 140 C
  
  <span class="mark mark--hole" style="left: 16.6%; top: 70.7%"></span>
  <span class="mark mark--hole" style="left: 58.6%; top: 69.5%"></span>
  <span class="mark mark--hole" style="left: 12.7%; top: 85.7%"></span>
  <span class="mark mark--hole" style="left: 62.5%; top: 84.1%"></span>
  <span class="mark mark--corner" style="left: 12.9%; top: 67.6%"></span>
  <span class="mark mark--corner" style="left: 63.4%; top: 66.8%"></span>
  <span class="mark mark--corner" style="left: 9.5%; top: 92.0%"></span>
  <span class="mark mark--corner" style="left: 70.8%; top: 89.9%"></span>
</div>

<div markdown>
[SHERPA Power Base L 140 C][sherpa-pb-l140c]

- **4 bolts down** M12 anchors, 100 mm into the slab
- **3 screws up** SHERPA 8 x 180 mm, into the column end
- **Blue** &mdash; the 4 bolt holes under each power base
- **Pink** &mdash; the 4 corners of each base plate

<!-- Only the coordinate lists are generated (by
     examples/example_model_23_assembly_step2.py, pulled in by section name).
     The headings and the note under them are prose - edit them here. -->

**Bolt holes to mark (blue)**

--8<-- "data/assembly/assembly_step2_points.md:holes"

**Base plate corners to measure (pink)**

--8<-- "data/assembly/assembly_step2_points.md:corners"

**Tower legs to mark (blue centre, pink plate)**

A 1500 &times; 1520 mm rectangle, diagonals equal to 0.000 mm.

--8<-- "data/assembly/assembly_step2_points.md:tower"

All at `z = 0`, in millimetres on the building grid.

[Assembly instructions (PDF)][sherpa-pb-c-manual] &middot;
[video][sherpa-pb-video]
</div>

  [sherpa-pb-l140c]: https://www.sherpa-connector.com/en/produkte/power-base/power-base-c/3391_306_shop_SHERPA-Power-Base-L-140-C.aspx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
  [sherpa-pb-c-manual]: https://www.harrer.at/data/db/072017_SHERPA_Montageanleitung_PB_C.pdf
  [sherpa-pb-video]: https://www.youtube.com/watch?v=jxFHtDUMXdI

</div>

## Step 3 &mdash; Screw the connector heads onto the columns

<!-- `camera` carries the up vector, as in step 2. Edges are ON here and BLACK
     (`on,<r>,<g>,<b>,<threshold>`): nothing is coloured in this step, so the
     edges are what separate the column, the plate and the screws. The 45
     degree threshold leaves the 64-facet plate smooth - 5.6 degrees a facet -
     and only draws where the part really has an edge. -->

<span class="online_3d_viewer" data-model="_models/assembly_step3_preview.obj,_models/assembly_step3_preview.mtl" camera="-1800,-600,1100,400,1050,170,0,0,1" edgesettings="on,0,0,0,45"></span>

**Per column**

--8<-- "data/assembly/assembly_step3_points.md:spec"

**In total**

--8<-- "data/assembly/assembly_step3_points.md:totals"

## Step 4 &mdash; Stand the columns on the bases

<!-- `camera` here sets the DIRECTION and the up vector only: Online 3D Viewer
     fits the bounding sphere to the box on load, so whatever distance the eye
     is given is thrown away. Looking down the diagonal of the grid from a
     corner puts all four columns in the frame without one hiding another.

     The eye looks DOWN the diagonal at about 30 degrees, so the four bases
     read as a square - which is what the step is about - and no column hides
     another. Steeper than this and the slow orbit the viewers run starts
     swinging the bay out of the frame; 30 degrees stays centred all the way
     round.

     Zooming in is the `viewer-bay` wrapper, not the camera - see assets/extra.css.
     This is the first shot of the whole bay rather than one part, and in the
     wide box of the other steps a sphere that size comes out tiny.

     Edges ON and BLACK, 45 degree threshold - same reasoning as step 2. -->

<div class="viewer-bay">
<span class="online_3d_viewer" data-model="_models/assembly_step4_preview.obj,_models/assembly_step4_preview.mtl" camera="-6750,-7200,7200,0,0,1200,0,0,1" edgesettings="on,0,0,0,45"></span>
</div>

Each column is set down on the base its head plate was screwed into in step 3.
The coupling nut joins the two halves and the 150 &ndash; 200 mm adjustment
takes up the level. Columns are ghosted, so the screws and anchors show.

**Which column on which base**

--8<-- "data/assembly/assembly_step4_points.md:seating"

**In total**

--8<-- "data/assembly/assembly_step4_points.md:totals"

## Step 5 &mdash; Prop the columns and stand the tower

<!-- Same wide-bay treatment as step 4: the `viewer-bay` wrapper does the
     zooming (Online 3D Viewer fits the model when it loads), and the camera
     sets the direction - about 30 degrees above the diagonal. This model is
     wider than step 4's, since the prop feet stand 2.5 m out from every
     column, so the eye is further back again. -->

<div class="viewer-bay">
<span class="online_3d_viewer" data-model="_models/assembly_step5_preview.obj,_models/assembly_step5_preview.mtl" camera="-9840,-10320,8720,0,0,1400,0,0,1" edgesettings="on,0,0,0,45"></span>
</div>

Before the floor goes up, the columns are propped and a tower goes up in the
middle:

- **8 raking props** &mdash; two per column at 45&deg;, clamped at `z = 2500`,
  base plates 2586 mm away along the slab
- **1 tower** at the centre, top at `z = 3303` &mdash; 197 mm under the column
  tops, deck inside the oculus opening

The tower stands on its four leg marks from step 2. The props need no marks.

**In total**

--8<-- "data/assembly/assembly_step5_points.md:totals"

## Step 6 &mdash; Land the first quarter

<!-- Steps 6 to 8 build the floor up one set of parts at a time: what is already
     standing is ghosted, what this step adds is solid. Same wide-bay wrapper
     and 30-degree diagonal as steps 4 and 5. -->

<div class="viewer-bay">
<span class="online_3d_viewer" data-model="_models/assembly_step6_preview.obj,_models/assembly_step6_preview.mtl" camera="-8400,-8850,6700,0,0,2200,0,0,1" edgesettings="on,0,0,0,45"></span>
</div>

The first quarter goes on with the two steel plates that tie it into the column
head, and their dowels. Columns and bases are ghosted.

**In total**

--8<-- "data/assembly/assembly_step6_points.md:totals"

**Dowels, in the plate's own frame**

--8<-- "data/assembly/assembly_step6_points.md:dowels"

## Step 7 &mdash; The other three quarters

<div class="viewer-bay">
<span class="online_3d_viewer" data-model="_models/assembly_step7_preview.obj,_models/assembly_step7_preview.mtl" camera="-8400,-8850,6700,0,0,2200,0,0,1" edgesettings="on,0,0,0,45"></span>
</div>

The remaining three quarters, each with its own pair of steel plates and dowels.
The four seams between quarters close as they land, and an outer-rib connector
ties each one.

**In total**

--8<-- "data/assembly/assembly_step7_points.md:totals"

**Seams**

--8<-- "data/assembly/assembly_step7_points.md:seams"

## Step 8 &mdash; Close the oculus

<div class="viewer-bay">
<span class="online_3d_viewer" data-model="_models/assembly_step8_preview.obj,_models/assembly_step8_preview.mtl" camera="-7000,-7300,6400,0,0,2900,0,0,1" edgesettings="on,0,0,0,45"></span>
</div>

The ring goes in last of the floor parts, off the tower deck standing under it.

**In total**

--8<-- "data/assembly/assembly_step8_points.md:totals"

**Where each quarter meets the ring**

--8<-- "data/assembly/assembly_step8_points.md:ring"

## Step 9 &mdash; Drive the wedges

<div class="viewer-bay">
<span class="online_3d_viewer" data-model="_models/assembly_step9_preview.obj,_models/assembly_step9_preview.mtl" camera="-7000,-7300,6800,0,0,3100,0,0,1" edgesettings="on,0,0,0,45"></span>
</div>

The wedges lock the seams and the oculus, each held by its own screws. The floor
is ghosted so the wedges and screws read.

**In total**

--8<-- "data/assembly/assembly_step9_points.md:totals"

**Each wedge**

--8<-- "data/assembly/assembly_step9_points.md:wedges"

</div>

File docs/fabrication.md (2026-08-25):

---
hide:
  - toc
---

# Parts

<!-- The Image column embeds an interactive 3D preview per part
     (assets/o3dv-init.js builds the viewers lazily, click one to expand it).
     The cells hold <span class="online_3d_viewer">, NOT <div> - block HTML
     breaks the markdown table parser. The Script column names the example
     that writes the part's fabrication files to data/fabrication/. Links use
     reference definitions at the bottom of this file, so a row stays one
     short readable line. Run `python tools/print_part_table.py` to see any
     table aligned in the terminal. -->

<div class="part-list" markdown="block">

### Whole model

| Part | Image | Files | Script | Dimensions (mm) | Qty | Material |
| --- | :---: | --- | --- | --- | ---: | --- |
| Full model | <span class="online_3d_viewer" data-model="_models/model_0_preview.obj" camera="9000,-9000,6000,0,0,1507,0,0,1"></span> | [STEP][model-stp] [OBJ][model-obj] [IFC][model-ifc] | [fab_model.py][model-py] | 6000 x 6000 x 3014 | 1 ||

### Column

| Part | Image | Files | Script | Dimensions (mm) | Qty | Material |
| --- | :---: | --- | --- | --- | ---: | --- |
| Column | <span class="online_3d_viewer" data-model="_models/column_0_preview.obj"></span> | [STEP][column-stp] [OBJ][column-obj] [IFC][column-ifc] | [fab_column.py][column-py] | 220 x 220 x 3350 incl. capitel<br>capitel 340 x 340 x 730 | 4 | Spruce |

### Floor quarter

| Part | Image | Files | Script | Dimensions (mm) | Qty | Material |
| --- | :---: | --- | --- | --- | ---: | --- |
| Outer rib | <span class="online_3d_viewer" data-model="_models/outer_ribs_0_0_preview.obj" camera="2500,-2100,1650,291,133,50,0,0,1"></span> | [STEP][outer-rib-stp] [OBJ][outer-rib-obj] [IFC][outer-rib-ifc] | [fab_outer_rib.py][outer-rib-py] | 2780 x 695 x 100 | 8 | Spruce |
| Inner rib | <span class="online_3d_viewer" data-model="_models/inner_ribs_0_0_preview.obj" camera="2500,-2100,1650,291,133,50,0,0,1"></span> | [STEP][inner-rib-stp] [OBJ][inner-rib-obj] [IFC][inner-rib-ifc] | [fab_inner_rib.py][inner-rib-py] | 3018 x 2026 x 60 | 8 | Spruce |
| Inner beam 1 | <span class="online_3d_viewer" data-model="_models/inner_beams_0_0_preview.obj" camera="1550,-1550,1150,0,6,30,0,0,1"></span> | [STEP][beam1-stp] [OBJ][beam1-obj] [IFC][beam1-ifc] | [fab_inner_beam_1.py][beam1-py] | 197 x 1985 x 60 | 4 | Spruce |
| Inner beam 2 | <span class="online_3d_viewer" data-model="_models/inner_beams_1_0_preview.obj" camera="900,-900,650,0,0,39,0,0,1"></span> | [STEP][beam2-stp] [OBJ][beam2-obj] [IFC][beam2-ifc] | [fab_inner_beam_2.py][beam2-py] | 1105 x 1105 x 80 | 4 | Spruce |
| Inner beam 3 | <span class="online_3d_viewer" data-model="_models/inner_beams_2_0_preview.obj" camera="1550,-1550,1150,6,0,30,0,0,1"></span> | [STEP][beam3-stp] [OBJ][beam3-obj] [IFC][beam3-ifc] | [fab_inner_beam_3.py][beam3-py] | 1985 x 197 x 60 | 4 | Spruce |
| T-section | <span class="online_3d_viewer" data-model="_models/tsections_0_preview.obj" camera="2500,-1900,1900,-4,565,14,0,0,1"></span> | [STEP][tsection-stp] [OBJ][tsection-obj] [IFC][tsection-ifc] | [fab_tsections.py][tsection-py] | 3230 x 151 x 27 (x6) | 4 | Spruce |
| Bed | <span class="online_3d_viewer" data-model="_models/beds_0_preview.obj" camera="4650,-500,2300,1584,2546,14,0,0,1"></span> | [STEP][bed-stp] [OBJ][bed-obj] [IFC][bed-ifc] | [fab_beds.py][bed-py] | strip 1:<br>586 x 467 x 27<br>757 x 441 x 27<br>1047 x 435 x 27<br>1336 x 431 x 27<br>1626 x 428 x 27<br>1875 x 367 x 27<br>strip 2:<br>687 x 314 x 27<br>521 x 505 x 27<br>696 x 516 x 27<br>887 x 512 x 27<br>1078 x 509 x 27<br>1242 x 436 x 27<br>strip 3:<br>726 x 426 x 27<br>757 x 441 x 27<br>1047 x 435 x 27<br>1336 x 431 x 27<br>1626 x 428 x 27<br>1875 x 367 x 27 | 4 | Spruce |

### Oculus

| Part | Image | Files | Script | Dimensions (mm) | Qty | Material |
| --- | :---: | --- | --- | --- | ---: | --- |
| Oculus plate | <span class="online_3d_viewer" data-model="_models/oculus_plate_0_preview.obj" camera="1812,-518,829,647,647,14,0,0,1"></span> | [STEP][oculus-plate-stp] [OBJ][oculus-plate-obj] [IFC][oculus-plate-ifc] | [fab_oculus.py][oculus-py] | 1294 x 1294 x 27 | 1 | Spruce |
| Oculus side plate | <span class="online_3d_viewer" data-model="_models/oculus_side_plates_0_preview.obj" camera="1896,-675,883,677,544,30,0,0,1"></span> | [STEP][oculus-side-plate-stp] [OBJ][oculus-side-plate-obj] [IFC][oculus-side-plate-ifc] | [fab_oculus.py][oculus-py] | 1354 x 197 x 60 (x4) | 1 | Spruce |
| Oculus side t-section | <span class="online_3d_viewer" data-model="_models/oculus_side_tsections_0_preview.obj" camera="1774,-936,812,634,204,14,0,0,1"></span> | [STEP][oculus-side-tsection-stp] [OBJ][oculus-side-tsection-obj] [IFC][oculus-side-tsection-ifc] | [fab_oculus.py][oculus-py] | 1267 x 27 x 27 (x4) | 1 | Spruce |

### Connectors

| Part | Image | Files | Script | Dimensions (mm) | Qty | Material |
| --- | :---: | --- | --- | --- | ---: | --- |
| Column base | <span class="online_3d_viewer" data-model="_models/support_0_preview.obj" camera="300,-300,200,0,0,75,0,0,1"></span> | [STEP][support-stp] [OBJ][support-obj] [IFC][support-ifc] | [fab_feet.py][support-py] | 140 x 140 x 150 | 4 | Steel, Sherpa Power Base 150402_PB_L-140-C (head plate Ø106 x 12, base plate 140 x 140 x 12 with 4 x Ø15 holes) |
| Inner beam wedge | <span class="online_3d_viewer" data-model="_models/wedges_inner_beams_0_preview.obj" camera="1810,-535,1250,310,966,150,0,0,1"></span> | [STEP][wedge-stp] [OBJ][wedge-obj] [IFC][wedge-ifc] | [fab_inner_beam_wedge.py][wedge-py] | 621 x 536 x 240 (x2)<br>577 x 435 x 300 | 4 | Spruce |
| Column-rib connector | <span class="online_3d_viewer" data-model="_models/connector_0_preview.obj" camera="509,-509,397,0,0,15,0,0,1"></span> | [STEP][connector-stp] [OBJ][connector-obj] [IFC][connector-ifc] | [fab_connectors.py][connectors-py] | 485 x 250 x 30 | 8 | Steel |
| Contact wedge | <span class="online_3d_viewer" data-model="_models/connector_wedge_0_preview.obj" camera="1200,-1200,900,0,0,31,0,0,1"></span> | [STEP][contact-wedge-stp] [OBJ][contact-wedge-obj] [IFC][contact-wedge-ifc] | [fab_connectors.py][connectors-py] | 1699 x 211 x 63 (x4)<br>1039 x 211 x 63 (x4) | 8 | Baubuche LVL |
| Outer rib connector | <span class="online_3d_viewer" data-model="_models/outer_rib_connector_0_preview.obj" camera="840,-840,650,0,0,20,0,0,1"></span> | [STEP][outer-conn-stp] [OBJ][outer-conn-obj] [IFC][outer-conn-ifc] | [fab_connectors.py][connectors-py] | 800 x 70 x 40 | 4 | Steel |
| Dowels, column side | <span class="online_3d_viewer" data-model="_models/dowel_0_preview.obj" camera="90,-90,88,0,0,25,0,0,1"></span> | [STEP][dowel-stp] [OBJ][dowel-obj] [IFC][dowel-ifc] | [fab_connectors.py][connectors-py] | 100 x Ø49 | 32 | Hardwood |
| Bolt | <span class="online_3d_viewer" data-model="_models/bolt_0_preview.obj" camera="144,-144,110,0,0,9,0,0,1"></span> | [STEP][bolt-stp] [OBJ][bolt-obj] [IFC][bolt-ifc] | [fab_connectors.py][connectors-py] | 160 x Ø18 | 32 | Steel |

</div>

<!-- Reference links for the part tables. The downloads are the files the
     example_model_12_fab_* scripts write to data/fabrication/, served by the
     site itself at _models/ (hooks/fabrication_assets.py) so they work on
     mkdocs serve and on every published version. The Script links open the
     example on GitHub - those resolve once the branch is merged to main. -->

[model-stp]: _models/model_0_fab.stp
[model-obj]: _models/model_0_fab.obj
[model-ifc]: _models/model_0_fab.ifc
[column-stp]: _models/column_0_fab.stp
[column-obj]: _models/column_0_fab.obj
[column-ifc]: _models/column_0_fab.ifc
[support-stp]: _models/support_0_fab.stp
[support-obj]: _models/support_0_fab.obj
[support-ifc]: _models/support_0_fab.ifc
[outer-rib-stp]: _models/outer_ribs_0_0_fab.stp
[outer-rib-obj]: _models/outer_ribs_0_0_fab.obj
[outer-rib-ifc]: _models/outer_ribs_0_0_fab.ifc
[inner-rib-stp]: _models/inner_ribs_0_0_fab.stp
[inner-rib-obj]: _models/inner_ribs_0_0_fab.obj
[inner-rib-ifc]: _models/inner_ribs_0_0_fab.ifc
[beam1-stp]: _models/inner_beams_0_0_fab.stp
[beam1-obj]: _models/inner_beams_0_0_fab.obj
[beam1-ifc]: _models/inner_beams_0_0_fab.ifc
[beam2-stp]: _models/inner_beams_1_0_fab.stp
[beam2-obj]: _models/inner_beams_1_0_fab.obj
[beam2-ifc]: _models/inner_beams_1_0_fab.ifc
[beam3-stp]: _models/inner_beams_2_0_fab.stp
[beam3-obj]: _models/inner_beams_2_0_fab.obj
[beam3-ifc]: _models/inner_beams_2_0_fab.ifc
[tsection-stp]: _models/tsections_0_fab.stp
[tsection-obj]: _models/tsections_0_fab.obj
[tsection-ifc]: _models/tsections_0_fab.ifc
[bed-stp]: _models/beds_0_fab.stp
[bed-obj]: _models/beds_0_fab.obj
[bed-ifc]: _models/beds_0_fab.ifc
[oculus-plate-stp]: _models/oculus_plate_0_fab.stp
[oculus-plate-obj]: _models/oculus_plate_0_fab.obj
[oculus-plate-ifc]: _models/oculus_plate_0_fab.ifc
[oculus-side-plate-stp]: _models/oculus_side_plates_0_fab.stp
[oculus-side-plate-obj]: _models/oculus_side_plates_0_fab.obj
[oculus-side-plate-ifc]: _models/oculus_side_plates_0_fab.ifc
[oculus-side-tsection-stp]: _models/oculus_side_tsections_0_fab.stp
[oculus-side-tsection-obj]: _models/oculus_side_tsections_0_fab.obj
[oculus-side-tsection-ifc]: _models/oculus_side_tsections_0_fab.ifc
[wedge-stp]: _models/wedges_inner_beams_0_fab.stp
[wedge-obj]: _models/wedges_inner_beams_0_fab.obj
[wedge-ifc]: _models/wedges_inner_beams_0_fab.ifc
[connector-stp]: _models/connector_0_fab.stp
[connector-obj]: _models/connector_0_fab.obj
[connector-ifc]: _models/connector_0_fab.ifc
[contact-wedge-stp]: _models/connector_wedge_0_fab.stp
[contact-wedge-obj]: _models/connector_wedge_0_fab.obj
[contact-wedge-ifc]: _models/connector_wedge_0_fab.ifc
[outer-conn-stp]: _models/outer_rib_connector_0_fab.stp
[outer-conn-obj]: _models/outer_rib_connector_0_fab.obj
[outer-conn-ifc]: _models/outer_rib_connector_0_fab.ifc
[dowel-stp]: _models/dowel_0_fab.stp
[dowel-obj]: _models/dowel_0_fab.obj
[dowel-ifc]: _models/dowel_0_fab.ifc
[bolt-stp]: _models/bolt_0_fab.stp
[bolt-obj]: _models/bolt_0_fab.obj
[bolt-ifc]: _models/bolt_0_fab.ifc

[model-py]: https://github.com/BRG-research/compas_tf/blob/main/examples/example_model_12_fab_model.py
[column-py]: https://github.com/BRG-research/compas_tf/blob/main/examples/example_model_12_fab_column.py
[support-py]: https://github.com/BRG-research/compas_tf/blob/main/examples/example_model_12_fab_feet.py
[outer-rib-py]: https://github.com/BRG-research/compas_tf/blob/main/examples/example_model_12_fab_outer_rib.py
[inner-rib-py]: https://github.com/BRG-research/compas_tf/blob/main/examples/example_model_12_fab_inner_rib.py
[beam1-py]: https://github.com/BRG-research/compas_tf/blob/main/examples/example_model_12_fab_inner_beam_1.py
[beam2-py]: https://github.com/BRG-research/compas_tf/blob/main/examples/example_model_12_fab_inner_beam_2.py
[beam3-py]: https://github.com/BRG-research/compas_tf/blob/main/examples/example_model_12_fab_inner_beam_3.py
[tsection-py]: https://github.com/BRG-research/compas_tf/blob/main/examples/example_model_12_fab_tsections.py
[bed-py]: https://github.com/BRG-research/compas_tf/blob/main/examples/example_model_12_fab_beds.py
[oculus-py]: https://github.com/BRG-research/compas_tf/blob/main/examples/example_model_12_fab_oculus.py
[wedge-py]: https://github.com/BRG-research/compas_tf/blob/main/examples/example_model_12_fab_inner_beam_wedge.py
[connectors-py]: https://github.com/BRG-research/compas_tf/blob/main/examples/example_model_12_fab_connectors.py

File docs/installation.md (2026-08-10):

# Installation

## Install it

```bash
pip install compas_tf
```

Needs Python 3.10 or newer. That is everything you need to open a model, walk
it, cut a piece out of it and write STEP.

Did it work?

```bash
python -c "import compas_tf; print(compas_tf.__version__)"
```

## Add the viewer

```bash
pip install compas_viewer
```

Optional. Only the drawing needs it - every example ends in `viewer.show()`.

## Get uv

[uv](https://github.com/astral-sh/uv) builds and manages the environment for
you - no activating, no `pip`. Install it once
([full instructions](https://docs.astral.sh/uv/getting-started/installation/)):

=== "Windows"

    ```powershell
    winget install --id=astral-sh.uv -e
    ```

    Or without winget:

    ```powershell
    powershell -ExecutionPolicy ByPass -c "irm https://astral.sh/uv/install.ps1 | iex"
    ```

=== "macOS / Linux"

    ```bash
    curl -LsSf https://astral.sh/uv/install.sh | sh
    ```

    Or `brew install uv`.

Then `uv --version` should answer, and `uv self update` keeps it current.

## Start a project with uv

```bash
uv init my-project
cd my-project
uv add compas_tf
uv run my_script.py
```

`uv add` writes the dependency into `pyproject.toml` and installs it; `uv run`
runs your script in that environment, creating it on the first call.
[Set up a project](examples/040_project_setup.md) is a complete one, file by
file.

## Work on this repository

Here you want an environment you stay inside, so make one and activate it:

```bash
git clone https://github.com/BRG-research/compas_tf.git
cd compas_tf

uv venv .venv --python 3.12
source .venv/Scripts/activate      # Linux / macOS: source .venv/bin/activate

uv pip install -r requirements.txt -r requirements-dev.txt -r requirements-viewer.txt
uv pip install -e .
```

!!! warning "Inside a `uv venv`, type `uv pip`, never `pip`"

    A `uv venv` has no `pip` in it - `which pip` finds nothing, and `python -m
    pip` says `No module named pip`. A bare `pip install` therefore falls
    through to some *other* Python on your `PATH` and installs there, where this
    project will never see it. `uv pip install` always targets the activated
    environment.

`-e` means editable: the package resolves to `src/compas_tf`, so your edits take
effect with no reinstall.

Did it work?

```bash
python -m pytest tests/ -q          # 11 passed
python tools/run_examples.py        # 21/21 ok
```

`run_examples.py` runs every example with the window suppressed and rewrites
everything in `data/`. Add numbers to run only some: `python tools/run_examples.py 19 20 21`.

## Two things that will trip you up

**Drawing Breps is slow unless you say this first.**

```python
from compas.tolerance import TOL

TOL.lineardeflection = 1.0
```

The default is `0.001` - a 1 micron tolerance on a 6 metre building. That is
2.93M triangles and 67 s, against 19.8k and 2.0 s at `1.0`, for the same
picture.

**The camera starts somewhere useless.** The model is in millimetres, the camera
is not, so you see nothing until you press ++f++. Do it in code instead:

```python
from compas_tf.viewer import zoom_to

zoom_to(viewer, [element.aabb for element in model.geometry_elements()])
```

## Build the docs

With the environment above activated:

```bash
uv pip install -r requirements-docs.txt

invoke serve      # live at http://127.0.0.1:8000, reloads as you edit
invoke docs       # one-off build into site/, fails on a broken link
```

??? info "What gets installed, and why"

    | Package | What it is for |
    | --- | --- |
    | `compas >= 2` | Geometry, datastructures, serialization. |
    | `compas_model` | Elements, the element tree, the interaction graph, contacts. |
    | `shapely` | The 2D polygon overlap behind contact detection. |
    | `compas_manifold >= 0.1.0` | Mesh booleans. Only when *building* a model; a baked one never calls it. |
    | `compas_occt >= 0.1.18` | The Brep/STEP kernel - `get_brep()`, `to_step()`, and the Brep scene object. |

    Python 3.9 is out because `shapely >= 2.1` needs 3.10. There is no upper
    bound: `compas_occt` and `compas_manifold` stop at a cp312 wheel, but it is
    a `cp312-abi3` wheel - built against the stable ABI - so it installs on 3.12
    and every CPython after it. Verified up to 3.14. CI tests on 3.10 across
    Linux, macOS and Windows; the examples and the published data files are
    produced on 3.12.

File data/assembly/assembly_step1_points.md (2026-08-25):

<!-- Generated by examples/example_model_23_assembly_step1.py - do not edit.
     The prose around these lists is in docs/assembly.md; only the
     numbers live here. -->

<!-- --8<-- [start:totals] -->
- 2 pieces on the bench &mdash; 1 quarter frame, 16 plates (18 beds go on later); 1 oculus, 9 plates
- quarter upside down &mdash; 3000 &times; 3000 mm on the bench, 701 mm tall
- oculus face down &mdash; 1414 &times; 1414 mm on the bench, 197 mm tall
- 1200 mm clear aisle between them, both set down on `z = 0`
- 5614 &times; 3000 mm of bench for the two side by side
- 2 jig boards &mdash; the piece's bounding box offset 100 mm all round, 50 mm thick, the piece cut out of it: 3200 &times; 3200 mm under the quarter, 1614 &times; 1614 mm under the oculus
<!-- --8<-- [end:totals] -->

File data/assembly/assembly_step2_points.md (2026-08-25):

<!-- Generated by examples/example_model_23_assembly_step3.py - do not edit.
     The prose around these lists is in docs/assembly.md; only the
     coordinates live here. -->

<!-- --8<-- [start:holes] -->
- `support_0` &mdash; (-2942, -2942) &middot; (-2838, -2942) &middot; (-2838, -2838) &middot; (-2942, -2838)
- `support_1` &mdash; (2838, -2942) &middot; (2942, -2942) &middot; (2942, -2838) &middot; (2838, -2838)
- `support_2` &mdash; (2838, 2838) &middot; (2942, 2838) &middot; (2942, 2942) &middot; (2838, 2942)
- `support_3` &mdash; (-2942, 2838) &middot; (-2838, 2838) &middot; (-2838, 2942) &middot; (-2942, 2942)
<!-- --8<-- [end:holes] -->

<!-- --8<-- [start:corners] -->
- `support_0` &mdash; (-2960, -2960) &middot; (-2820, -2960) &middot; (-2820, -2820) &middot; (-2960, -2820)
- `support_1` &mdash; (2820, -2960) &middot; (2960, -2960) &middot; (2960, -2820) &middot; (2820, -2820)
- `support_2` &mdash; (2820, 2820) &middot; (2960, 2820) &middot; (2960, 2960) &middot; (2820, 2960)
- `support_3` &mdash; (-2960, 2820) &middot; (-2820, 2820) &middot; (-2820, 2960) &middot; (-2960, 2960)
<!-- --8<-- [end:corners] -->

<!-- --8<-- [start:tower] -->
- `tower_leg_0` &mdash; (1068, -7) &middot; plate (1025, -7) &middot; (1068, -49) &middot; (1110, -7) &middot; (1068, 35)
- `tower_leg_1` &mdash; (-7, 1068) &middot; plate (-50, 1068) &middot; (-7, 1025) &middot; (35, 1068) &middot; (-7, 1110)
- `tower_leg_2` &mdash; (-1068, 7) &middot; plate (-1110, 7) &middot; (-1068, -35) &middot; (-1025, 7) &middot; (-1068, 50)
- `tower_leg_3` &mdash; (7, -1068) &middot; plate (-36, -1068) &middot; (7, -1110) &middot; (49, -1068) &middot; (7, -1025)
<!-- --8<-- [end:tower] -->

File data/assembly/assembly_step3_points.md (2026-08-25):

<!-- Generated by examples/example_model_23_assembly_step4.py - do not edit.
     The prose around these lists is in docs/assembly.md; only the
     numbers live here. -->

<!-- --8<-- [start:spec] -->
- 1 x head plate &mdash; &Oslash; 106 mm, 12 mm thick, let 12 mm into a pocket in the column end
- 3 x SHERPA screw 8 x 180 mm, driven at 25&deg; to each other into the end grain
<!-- --8<-- [end:spec] -->

<!-- --8<-- [start:totals] -->
- 4 columns &mdash; 4 head plates, 12 screws in total
<!-- --8<-- [end:totals] -->

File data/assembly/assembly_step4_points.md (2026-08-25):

<!-- Generated by examples/example_model_23_assembly_step5.py - do not edit.
     The prose around these lists is in docs/assembly.md; only the
     numbers live here. -->

<!-- --8<-- [start:seating] -->
- `column_0` stands on `support_0` &mdash; (-2890, -2890), foot at `z = 150` mm
- `column_1` stands on `support_1` &mdash; (2890, -2890), foot at `z = 150` mm
- `column_2` stands on `support_2` &mdash; (2890, 2890), foot at `z = 150` mm
- `column_3` stands on `support_3` &mdash; (-2890, 2890), foot at `z = 150` mm
<!-- --8<-- [end:seating] -->

<!-- --8<-- [start:totals] -->
- 4 columns, tops at `z = 3500` mm
- 28 fasteners &mdash; 16 anchors down into the slab, 12 screws up into the end grain
<!-- --8<-- [end:totals] -->

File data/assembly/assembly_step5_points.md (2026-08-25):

<!-- Generated by examples/example_model_23_assembly_step6.py - do not edit.
     The prose around these lists is in docs/assembly.md; only the
     numbers live here. -->

<!-- --8<-- [start:totals] -->
- 8 raking props &mdash; 2 per column, clamped at `z = 2500` mm, feet 2500 mm out on the slab (marked in step 2)
- 32 prop parts and 1 tower, 2453 &times; 2453 mm over the legs, top at `z = 3303` mm
- the tower stands on its 4 leg marks from step 2; the props need none - each clamps to a column and foots where that puts it
<!-- --8<-- [end:totals] -->

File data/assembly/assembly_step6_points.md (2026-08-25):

<!-- Generated by examples/example_model_23_assembly_step7.py - do not edit.
     The prose around these lists is in docs/assembly.md; only the
     numbers live here. -->

<!-- --8<-- [start:totals] -->
- 1 quarter of 4 &mdash; `quarter_model_0`, 34 plates, on `column_0`
- 11 bearing faces, 0.277 m&sup2;, gap 0.0000 mm, raked 8&ndash;10&deg; off vertical &mdash; no level seat, and no head plate up here
- 2 steel plates &mdash; 485 &times; 30 &times; 250 mm, 220 mm through the column head and 265 mm into the rib
- 8 dowels &mdash; &Oslash;50 &times; 100 mm, 35 mm bearing in the timber each side
- 6 steel plates and 24 dowels are left for step 7
<!-- --8<-- [end:totals] -->

<!-- --8<-- [start:dowels] -->
- `connector_0` on `column_0` into `quarter_model_0` &mdash; `cylinder_column_0` at -68.7, -75.0 mm, `cylinder_column_1` at -68.7, -175.0 mm, `cylinder_rib_0` at +113.8, -75.0 mm, `cylinder_rib_1` at +113.8, -175.0 mm
- `connector_1` on `column_0` into `quarter_model_0` &mdash; `cylinder_column_0` at -68.8, -75.0 mm, `cylinder_column_1` at -68.8, -175.0 mm, `cylinder_rib_0` at +113.7, -75.0 mm, `cylinder_rib_1` at +113.7, -175.0 mm
<!-- --8<-- [end:dowels] -->

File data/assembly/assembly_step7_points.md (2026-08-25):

<!-- Generated by examples/example_model_23_assembly_step8.py - do not edit.
     The prose around these lists is in docs/assembly.md; only the
     numbers live here. -->

<!-- --8<-- [start:totals] -->
- 3 quarters &mdash; 102 plates, 34 each, one per column
- 11 bearing faces per quarter, 0.277 m&sup2;, worst gap 0.0000 mm
- 6 steel plates and 24 dowels &mdash; the rest of the 8 and 32; 2 and 8 went on in step 6
- 4 seams closed, 3 faces each, worst gap 0.0000 mm
- 4 outer-rib connectors &mdash; 800 mm long, half into each rib
<!-- --8<-- [end:totals] -->

<!-- --8<-- [start:seams] -->
- `outer_rib_connector_0` closes `quarter_model_0` &harr; `quarter_model_1` &mdash; 8 faces a side, 0.068 m&sup2;, gap 0.0000 mm
- `outer_rib_connector_1` closes `quarter_model_0` &harr; `quarter_model_3` &mdash; 8 faces a side, 0.068 m&sup2;, gap 0.0000 mm
- `outer_rib_connector_2` closes `quarter_model_1` &harr; `quarter_model_2` &mdash; 8 faces a side, 0.068 m&sup2;, gap 0.0000 mm
- `outer_rib_connector_3` closes `quarter_model_2` &harr; `quarter_model_3` &mdash; 8 faces a side, 0.068 m&sup2;, gap 0.0000 mm
<!-- --8<-- [end:seams] -->

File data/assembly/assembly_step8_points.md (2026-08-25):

<!-- Generated by examples/example_model_23_assembly_step9.py - do not edit.
     The prose around these lists is in docs/assembly.md; only the
     numbers live here. -->

<!-- --8<-- [start:totals] -->
- 1 oculus &mdash; 9 plates, 2000 &times; 2000 mm, `z = 3303 .. 3500` mm
- 4 ring plates 197 mm deep, 4 bed plates and 1 centre plate 27 mm thick
- placed off the tower deck &mdash; deck top `z = 3303` mm, oculus soffit `z = 3303` mm, +0 mm between them
- 16 beam/ring pairs, 13 of them recorded as contacts; the 3 that are not still close to 0.0000 mm
- the four quarters agree with each other to 0.0000 mm under a quarter turn
<!-- --8<-- [end:totals] -->

<!-- --8<-- [start:ring] -->
- `quarter_model_0` &mdash; 4 recorded faces, 0.072 m&sup2;, gap 0.0000 mm
- `quarter_model_1` &mdash; 4 recorded faces, 0.072 m&sup2;, gap 0.0000 mm
- `quarter_model_2` &mdash; 1 recorded face, 0.010 m&sup2;, gap 0.0000 mm
- `quarter_model_3` &mdash; 4 recorded faces, 0.072 m&sup2;, gap 0.0000 mm
<!-- --8<-- [end:ring] -->

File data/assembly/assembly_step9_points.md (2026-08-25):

<!-- Generated by examples/example_model_23_assembly_step9.py - do not edit.
     The prose around these lists is in docs/assembly.md; only the
     numbers live here. -->

<!-- --8<-- [start:totals] -->
- 8 wedges &mdash; 4 on the seams between quarters, 4 around the oculus
- 1039, 1699 mm long, 208.5 mm from apex to back face, 63.5 mm across the back
- 32 screws &mdash; &Oslash;20 &times; 160 mm, 3 to a short wedge and 5 to a long one
- every screw level to 0.0000 mm, through 29.5 mm of wedge, 65 mm into the timber each side
- worst gap in a pocket 0.0000 mm; the wedges stand +12 to +14 mm proud of the floor top
<!-- --8<-- [end:totals] -->

<!-- --8<-- [start:wedges] -->
- `connector_wedge_0` &mdash; 1699 mm, locks `quarter_model_0` &harr; `quarter_model_1`, 5 screws, 3 faces a side, gap 0.0000 mm
- `connector_wedge_1` &mdash; 1039 mm, locks `oculus` &harr; `quarter_model_0`, 3 screws, 3 faces a side, gap 0.0000 mm
- `connector_wedge_2` &mdash; 1699 mm, locks `quarter_model_0` &harr; `quarter_model_3`, 5 screws, 3 faces a side, gap 0.0000 mm
- `connector_wedge_3` &mdash; 1699 mm, locks `quarter_model_1` &harr; `quarter_model_2`, 5 screws, 3 faces a side, gap 0.0000 mm
- `connector_wedge_4` &mdash; 1039 mm, locks `oculus` &harr; `quarter_model_1`, 3 screws, 3 faces a side, gap 0.0000 mm
- `connector_wedge_5` &mdash; 1699 mm, locks `quarter_model_2` &harr; `quarter_model_3`, 5 screws, 3 faces a side, gap 0.0000 mm
- `connector_wedge_6` &mdash; 1039 mm, locks `oculus` &harr; `quarter_model_2`, 3 screws, 3 faces a side, gap 0.0000 mm
- `connector_wedge_7` &mdash; 1039 mm, locks `oculus` &harr; `quarter_model_3`, 3 screws, 3 faces a side, gap 0.0000 mm
<!-- --8<-- [end:wedges] -->

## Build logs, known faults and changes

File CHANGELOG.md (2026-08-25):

# Changelog

All notable changes to this project will be documented in this file.

The format is based on [Keep a Changelog](https://keepachangelog.com/en/1.0.0/),
and this project adheres to [Semantic Versioning](https://semver.org/spec/v2.0.0.html).

## Unreleased

### Added

* Added `docs/fabrication.md`, the part list for the shop, and a `Fabrication` section in `mkdocs.yml` holding it. One row per part family in `data/cantilevers_baked_model.json` - all 237 elements - with quantity, the oriented bounding box of the finished part in millimetres (longest side first, a range where the family varies), material, and empty `Image` and `3D model` cells to fill in as the per-part files come out of the scripts. Material is only filled where the code states it: the column is glulam, the base is the Sherpa Power Base `150402_PB_L-140-C` named in `SupportElement`.

* Added `compas_tf.viewer.dump_scene`, which writes the Rhino bundle by walking the finished viewer scene, and `scene_nodes`, the flattening behind it. Each object contributes the one colour Rhino can show - an explicit `color=`, else the colour of the buffer its geometry is drawn in, so a polyline keeps its `linecolor` instead of inheriting a surface grey.

* Added six assembly steps to `docs/assembly.md` and the scripts behind them, so the page carries the whole sequence rather than its first two steps: `example_model_23_assembly_step1.py` (the shop - a quarter frame upside down in a jig with the oculus beside it), `_step4` (columns set down on their bases), `_step5` (raking props and the centre tower), `_step6` (the first quarter, with the column steel plates and dowels), `_step7` (the other three quarters and the outer-rib connectors), `_step8` (the oculus) and `_step9` (the wedges and their screws). Each ghosts what is already standing and draws solid what it adds, and each prints the fit it claims - the eight prop clamps meet the 220 shaft at 0.000 mm, the tower's four legs come out on a 1500 x 1520 mm rectangle whose diagonals agree to 0.000 mm, every quarter lands on its column over 11 faces and 0.277 m2 at 0.000 mm, and all 32 wedge screws are level to 0.000 mm.

* Added `examples/assembly_shoring.py`, the prop and tower layout two steps need: step 2 stakes out the tower's legs and step 5 stands the props and the tower on them. It follows `example_model_10_shoring.py` - two props per column at right angles, clamped at 2500 and reaching 2500 along the slab - and exists so the marks and the parts cannot drift apart. A number typed twice is a number that drifts.

* Added `.side-by-side` and `.viewer-bay` to `docs/assets/extra.css`. The first puts an image and its text in two columns and stacks them below 60em; the second gives a whole-bay viewer a taller, squarer box, which is the only thing that actually zooms one in - Online 3D Viewer fits the model's bounding sphere on load, so a `camera` attribute sets the direction and the up vector and its distance is thrown away.

* Added `.marked-photo` and the marks on the SHERPA photograph in step 2: eight dots positioned in per cent of the image, so they scale with it, in the BLUE and PINK of the survey preview beside it. The positions were measured off the image rather than eyed in - the four blue ones are the darkest-blob centroids of the bolt holes, the four pink ones the extremes of the plate's own silhouette against the wood.

* Added `docs/_images/quarter_and_oculus_in_jig.jpg`, the shop photograph of a quarter and an oculus element in their trays, beside step 1's preview of the same two pieces.

### Changed

* Changed every example to draw through `viewer.scene` - `viewer.scene.add(item, parent=group, ...)` and `viewer.scene.add_group(name, parent=group)` - instead of a group handle's own `add`. A group handle's `add` is core compas' `Group.add`, which goes straight to `SceneObject.add` and never sees `compas_viewer.Scene.add`'s `facecolor` -> `surfacecolor` translation, so `facecolor=` on a group was silently dropped (`example_model_1`'s construction planes drew grey, not blue).
* Changed `SchoringElement.from_points_and_vectors`, `from_points_and_vectors_no_foot_no_head` and `polylines_to_models` to build a `TFModel` instead of a plain `compas_model.models.Model`. `duplicate()` - re-clone every element with a fresh guid so the copies can be merged alongside the original - is defined on this project's `BaseModel`, not upstream, so `example_model_10_shoring.py` died on `'Model' object has no attribute 'duplicate'` and took `example_model_11_full.py` with it (it reads `shoring_model.json`). These were the last plain-`Model` constructions in `src/`.
* Changed `FloorGuide.bay_height` back to 3500. It went 3500 -> 3000 in `a9fb6f3` "column fab wip" (2026-06-24), one line inside a 25-file commit, and every column has been 500 mm short since: `example_model_2_column_model.py` builds the column as `bay_height - SupportElement.HEIGHT`, so they ran `z = 150 .. 3000` instead of `150 .. 3500`. The whole chain is regenerated from it - floorguide, column, columns, quarters, oculus, floor, cantilever(s), the baked model and its STEP, the shoring and full models, the fabrication files and all nine assembly previews. `story_height = 3200` in `example_model_10_shoring.py` was tuned to the 3500 bay and is right again; it is still hardcoded there and still does not read `guide.bay_height`.

* Changed the assembly series to nine numbered steps, shifting the existing ones by one to make room for the shop step at the front: the survey is step 2, the head plates 3, the columns 4. Scripts, `STEP` constants, preview and fragment filenames, page headings, `_models/` paths, snippet paths, the `#step-N-...` anchors and the cross-references inside the scripts' own docstrings all moved together, so any link into `docs/assembly.md` from outside the repo is off by one.

* Changed `write_colored_obj` to triangulate every face by ear clipping in the face's own plane, instead of writing the tessellation's polygons and leaving them to the viewer. Viewers fan an n-gon from its first vertex, which is correct only for a convex one, and 64 of the 2028 polygon faces in this model are concave - the faces the boolean cuts create, up to 12 vertices. Fanned, their triangles fold across the notch and spill outside the outline, so sound booleans rendered as if they had failed. Triangle areas match the polygon areas to 5e-8 mm2.

* Changed `example_model_11_full.py` to merge `data/cantilevers_model.json`. It read `cantilever_model.json` - example 7's SINGLE column and quarter - so `full_model.json` was one quarter of the structure inside the complete shoring ring: 119 elements and 1 column. It is 362 elements and 4 columns.

* Changed the assembly page so only numbers are generated. The scripts used to write their own headings and sentences into `data/assembly/assembly_step*_points.md`, which made the wording unreachable from `docs/assembly.md`; each list is now wrapped in a snippet section (`--8<-- "...:holes"`) and the prose around it is ordinary markdown on the page.

* Changed the assembly previews to one colour. Every object is the same steel, and blue and pink now mean only "mark" - points to drill and footprints to measure - which is the whole subject of step 2 and appears in no other step. The jig boards of step 1 are that colour drawn at `d 0.4`, so the pocket under the piece can be seen.

* Changed step 2 to stake out the tower's four legs in the same session as the column bases, since the instrument is already up on the centre of the bay and a second set-up is a second chance to be wrong. Its shot is the whole floor rather than a 0.7 m close-up of `support_0` because of it. The props are not staked out: each clamps to a column and foots where that puts it.

* Changed `docs/fabrication.md`'s column row to `220 x 220 x 3350 incl. capitel`, which is what a 3500 bay gives.

* Changed the examples' `color=(0.85, 0.85, 0.85)` to `facecolor=`. `compas.scene.GeometryObject.__init__` fills `pointcolor`, `linecolor` AND `surfacecolor` from `color`, so one `color=` painted the edges the same grey as the faces and the wireframe disappeared. The viewer's own defaults - `linecolor` 0.2 grey, `surfacecolor` 0.9 grey - only survive when `color` is left unset. Examples 4, 5, 6, 7, 10 and 11 were drawing flat because of it.

### Removed

* Removed `compas_tf.viewer.TeeScene`, `SceneRecorder`, `dump_bundle` and the `_patch_group_nesting` monkeypatch that gave `compas_viewer`'s `Group` an `add_group`. The fab examples drew through the tee so the Rhino bundle could be recorded alongside; `dump_scene` reads the scene itself, so the examples use the stock viewer API and the bundle is what the viewer actually shows. The tee also dropped a group's style kwargs on the live side and kept only a fixed list of style keys.

## [0.1.12] 2026-08-10

### Added

### Changed

* Changed `docs/installation.md` to say how to get uv, per platform - `winget install --id=astral-sh.uv` or the `astral.sh/uv/install.ps1` script on Windows, `astral.sh/uv/install.sh` or Homebrew elsewhere - with links to the repository and the official instructions. The page told you to run `uv init` without ever saying where `uv` comes from. Needs `pymdownx.tabbed`, which `mkdocs.yml` did not have.
* Changed the example pages to the minimum that is not already in the script beside them - 445 lines to 287. What is left per page is the screenshot, the script, its output, and only the facts the code does not show: the deflection numbers, why the contacts need a second STEP, why `neighbors=` takes types. `040_project_setup` gets the uv install link back and drops the `--optional viewer` / `uv sync --extra` pair for a plain `uv add compas_viewer`, both verified by running them into a scratch project.
* Changed the `release` workflow's build matrix to Python 3.10-3.12. It still ran 3.9, which `requires-python = ">=3.10"` now rejects, and the `publish` job needs the build - so the tag went up and nothing was published.

### Removed

* Removed `examples/example_model_15_fab_formwork.py`, `example_model_17_quantities.py` and their entries in `tools/run_examples.py`. Both were 0-byte files that the runner counted as passing and the pipeline page described as if they did something. The chain is 21 examples.
* Removed `tests/test_placeholder.py` - `assert True`, the stub that kept pytest from failing on an empty suite before there were real tests. 11 remain.

## [0.1.11] 2026-08-10

### Added

* Added `compas_tf.viewer.zoom_to`, which frames the camera on the geometry before `viewer.show()`. On a model in millimetres the viewer opens at `[-10, -10, 10]` with a far plane of 1000 (scaled by `camera.scale`, which starts at 1), so a 6015 mm building is entirely clipped until you press ++f++. compas_viewer's own `zoom_selected` cannot be called for you - it reads the scene objects' bounding boxes, which do not exist until the renderer has run - so this does the same arithmetic from `element.aabb` / `brep.aabb` instead, keeping the camera's existing view direction. Using `target - position` as `zoom_selected` does is degenerate before the first render: the default position sits almost on the origin, so on a model centred 1.5 m up the camera ends up underneath the building.

### Changed

* Changed `find_groups_with_names(neighbors=...)` to accept a tuple of element types, or a predicate, as well as a bool. `True` admits anything that touches the selection, which is rarely what an assembly means: across the seam a bay touches `outer_ribs_1_1`, `outer_ribs_0_3`, `inner_beams_2_1`, `inner_beams_0_3` and two oculus plates, so the extraction came out with 2-part fragments of `quarter_model_1`, `quarter_model_3` and `oculus_model` hanging off it. The filter applies to both passes, which matters more than it looks: under `True` the oculus arrives by contact and then `connector_wedge_7`'s cylinders arrive because their boxes overlap `oculus_3` - one wrong admission widening what the box pass tests against.
* Changed `example_model_21_extract_bay.py` to name only the hardware that mounts the cantilever on its column (`ConnectorElement`, `DowelCylinderElement`). The wedges and their bolts are inner-beam hardware and `OuterRibConnectorElement` joins one quarter to the next, so the bay is 46 elements and 143 contacts rather than 64 and 168. `docs/examples/030_extract_bay` gets the viewer screenshot of it.
* Changed `example_model_18` to `_22` to drop the timing scaffolding and the comment blocks the documentation now carries.
* Changed the docs to say how big anything is - 237 elements and 733 contacts in the building, 185 in the floor, 34 in a quarter, 46 in a bay - in the tutorial tree and the screenshot captions.
* Changed `requires-python` to `>=3.10`. It said `>=3.9`, which `shapely >= 2.1` rules out, and was briefly capped at `<3.13` on the assumption that `compas_occt` and `compas_manifold` stop at 3.12 - they ship a `cp312-abi3` wheel, built against the stable ABI, so it installs on every CPython from 3.12 on. Verified up to 3.14; the cap was what broke the docs workflow, which now pins 3.12 to match the local environment rather than out of necessity.

### Removed

## [0.1.10] 2026-08-10

### Added

* Added `examples/example_model_22_read_brep_adjacency.py` and `docs/examples/025_read_brep_adjacency`, which read the STEP model, the contact STEP and its JSON sidecar together. `020_read_brep` could draw the contacts but not say which two elements any of them joins, because STEP drops per-shape names; the sidecar describes face *i* in record *i*, so the pair is what turns 733 anonymous faces into 585 named joints, an area per pair and a type table.

### Changed

* Changed `docs/index.md` to a two-sentence description of what the package does, the project presentation, and direct download links for the current STEP model, its contacts and their sidecar. The code sample it opened with belonged in the examples, and there was no link to either the presentation or the model.
* Changed `requirements-dev.txt` to depend on `pytest` directly. It arrived transitively with `sphinx_compas2_theme`, so dropping that for mkdocs left the `build` workflow failing with `pytest: command not found` - lint green, tests never run.
* Changed `find_groups_with_names(neighbors=True)` to find the elements that have no interactions at all. It was a graph walk only, and the contact search skips the fasteners (`skip=involving(DowelCylinderElement, ConnectorCylinderElement)`, 74% of the contacts for no structural information), which leaves 64 of the 237 elements with no edge for a walk to follow: a bay came out with its connectors but without the 32 dowels and 32 cylinders that bolt them on. Geometry is the only signal left for those, so an unlinked element is now included when its bounding box lands inside the bay - applied to the unlinked only, because on elements the graph does describe a box test is far too loose, one diagonal rib's box swallowing half the floor. Bay 0 goes from 49 elements to 77 (+16 cylinders, +12 dowels).
* Changed `example_model_21_extract_bay.py` back to `neighbors=True`, which is now worth passing.

### Removed

* Removed `data/bay_model.stp` and the outputs of examples that no longer exist (`floor_model_booleans.json`, `schoring_models.json`, `orient_2d.json`, `unwrap_beds.json`/`.png`, `example_2_floor_model.obj`, `example_model_7_contacts_columns.obj`), plus the two `PLACEHOLDER` files that kept the now-populated `docs/_images` and `docs/examples` in git.

## [0.1.9] 2026-08-10

### Added

* Added `BaseModel.find_groups_with_names` - several named groups extracted at once as one standalone model, for lifting an assembly (one column plus the quarter it carries) out of the building. The plural matters: contacts BETWEEN the groups only survive if the groups come out together, so `find_group_with_name` twice plus `merge` keeps every internal contact and drops exactly the joint that connects them. Each group keeps its ancestor chain, pruned to what was asked for, so the extracted parts stay where they are in the world. `neighbors=True` also brings in the elements that interact with the extracted ones - the fasteners live in their own top-level groups, so a bay extracted by name alone has none - one step out only, or the whole model follows one edge at a time. On the cantilevers model: 49 elements and 208 contacts against 36 and 125 without.
* Added `examples/example_model_21_extract_bay.py`, and the documentation the reading side never had: `docs/examples/010_read_model`, `020_read_brep`, `030_extract_bay`, `040_project_setup` (a consumer project from scratch) and `050_pipeline`, plus a written `tutorial` and a populated API reference.

### Changed

* Changed `examples/example_model_19_read_model.py` and `example_model_20_read_brep.py` to the minimum API that does the job. What the comment blocks explained - baking, Brep contacts against mesh contacts, the STEP name/order sidecar, the deflection - is now prose in the docs, where it is read once rather than scrolled past in every example.
* Changed `README.md`, which still described a `compas_viewer` fork and an `example_0_watch_viewer.py` that no longer exist.

### Removed

## [0.1.8] 2026-08-10

### Added

### Changed

* Changed `PlateElement` to build its loft on first use instead of in `__init__`. `compute_elementgeometry` is the only reader and it is `@baked`, so a baked plate returned its stored mesh and the loft was thrown away unused - yet all 145 plates paid for it on every load. `compas.json_load` of the cantilevers model drops from 3.3 s to 0.60 s (the raw `json.loads` of the same 3.9 MB file is 0.09 s).

### Removed

## [0.1.7] 2026-08-10

### Added

* Added `compas_tf.contacts` - contact detection on Brep faces instead of mesh faces: `brep_brep_contacts`, `prepare_faces`, the `BrepContacts` element-pair detector (with a per-element Brep and face cache), the `involving` / `between` skip predicates, and the `contact_holes` accessor. The face pairs are prefiltered on opposite normals and boundary AABBs rather than by `Brep.overlap`, which would tessellate every Brep first - identical results, 3.8x faster, and no dependence on `TOL.lineardeflection`.
* Added `TFModel.compute_contacts_brep`, the one-call Brep version of the contact search, all-pairs or restricted to named groups.
* Added `TFModel.clear_contacts`, `TFModel.contact_pairs`, `TFModel.contact_breps`, `TFModel.contact_adjacency`, `TFModel.contacts_to_step` and `TFModel.contacts_to_json`. STEP drops per-shape names, so the contact faces carry no adjacency; it goes in a JSON sidecar keyed by index, which STEP does preserve.
* Added a `contactmethod` hook to `TFModel.compute_contacts` and `BaseModel.compute_contacts_between_groups`, so the spatial search can be driven by something other than `element.compute_contacts`.
* Added a `cache` argument to `TFModel.element_breps` and `TFModel.to_step`, to reuse Breps already built by a contact search.

### Changed

* Changed `example_model_18_write_model_and_brep.py` to compute contacts between all elements on the Brep faces, skipping the fasteners, and to write them to both the model JSON and their own STEP file.
* Changed `example_model_19_read_model.py` and `example_model_20_read_brep.py` to read the contacts instead of recomputing them.
* Changed `example_model_20_read_brep.py` to set `TOL.lineardeflection = 1.0`: at the 0.001 default the Breps tessellate to 2.93M triangles in 67 s, at 1.0 to 19.8k in 2.0 s, for the same picture. The old comment claiming the count was independent of the deflection was wrong.

### Removed

## [0.1.6] 2026-08-10

### Added

### Changed

### Removed

## [0.1.5] 2026-08-10

### Added

### Changed

### Removed

## [0.1.4] 2026-08-09

### Added

### Changed

### Removed

## [0.1.3] 2026-08-09

### Added

### Changed

### Removed

## [0.1.2] 2026-08-09

### Added

### Changed

### Removed

## [0.1.1] 2026-08-09

### Added

- Column head version based on column centered at the corner of a quarter.
- Dated whole-model OBJ export (`floor_model_<YYYY-MM-DD>.obj`, one named object per element) in `examples/example_2_floor_model_booleans.py`.
- `FloorModel.add_column_connections()` — places a `FloorColumnConnectionElement` on each column and carves the connector pocket out of the column and that quarter's two outer ribs via boolean difference.
- `FloorGuide.corner_point_column()` — column/support grid placement, moved off the removed `FloorBuilder`.
- `compas_manifold` as a runtime dependency (declared in `requirements.txt`).

### Changed

- **`FloorGuide` is now the single parametric source of the floor.** `FloorModel` is constructed from a guide (`FloorModel(guide=...)`, was `builder=...`) and serializes it under the `"guide"` key.
- **All mesh booleans now use `compas_manifold` exclusively** (difference, union, chain) — the `compas_cgal` fallback and dependency were removed. `compas_cgal` no longer in `requirements.txt`.
- `compute_contacts_inner_beams` no longer calls `precompute_boolean_modifiers` internally (the caller does it once), removing a duplicate boolean pass.
- Top docstring of `example_2` is a raw string (fixes the `\c` SyntaxWarning).
- `PolylineLoft.to_mesh`/`multiple_to_mesh` repair capped-loft face winding so lofted plates (e.g. t-sections) come out watertight.
- `PlateElement.compute_contacts` supports both `polygon_polygon_overlap` signatures across `compas_model` versions.
- Corner column-connection cutter is now drawn yellow instead of orange in the viewer.

### Removed

- **`FloorBuilder`** (`floor_builder.py`) and the legacy element family built on it: `QuarterFloorElement` (`quarter_floor.py`), `ColumnHeadElement` (`column_head.py`), `OculusElement` (`oculus.py`).
- `FloorModel.add_oculus()` (used the removed `OculusElement`; oculus geometry now comes from `guide.oculus`) and `build_model()` from `examples/model.py`.

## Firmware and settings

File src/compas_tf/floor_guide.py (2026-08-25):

import math

from compas.data import Data
from compas.geometry import Line
from compas.geometry import Plane
from compas.geometry import Point
from compas.geometry import Polygon
from compas.geometry import Polyline
from compas.geometry import Projection
from compas.geometry import Rotation
from compas.geometry import Translation
from compas.geometry import Vector
from compas.geometry import intersection_line_plane
from compas.geometry import intersection_plane_plane
from compas.geometry import intersection_plane_plane_plane

from compas_tf.brep import BrepMixin
from compas_tf.geometry import BezierCurve
from compas_tf.geometry import PolylineCut
from compas_tf.geometry import PolylineOffset
from compas_tf.plate import PlateElement


class FloorGuide(Data, BrepMixin):
    """Provides geometry parameters for building column heads and edge beams.

    Depending if the column is bigger than column head, there is either cutters of a beam of a separate block.
    """

    def __init__(
        self,
        size_grid_x=3000,
        size_grid_y=3000,
        size_column_head=250,
        size_column_head_chamfer=100,
        size_outer_ribs=100,
        size_inner_ribs=60,
        size_inner_beams=60,
        size_wedge=100,
        size_tsections=27,
        height=650,
        rise=453,
        size_oculus=1000,
        wedge_plane_angle=-10,
        bay_height=3500,
    ):
        super().__init__()

        self.size_grid_x = size_grid_x
        self.size_grid_y = size_grid_y

        self.size_column_head = size_column_head
        self.size_column_head_chamfer = size_column_head_chamfer

        self.size_oculus = size_oculus
        self.size_oculus_x = size_oculus * size_grid_x / size_grid_y
        self.size_oculus_y = size_oculus * size_grid_y / size_grid_x

        self.size_outer_ribs = size_outer_ribs
        self.size_inner_ribs = size_inner_ribs
        self.size_inner_beams = size_inner_beams
        self.size_wedge = size_wedge
        self.size_tsections = size_tsections

        # Gentle tilt (degrees) of the wedge planes that cut the ribs / wedges /
        # beds / t-sections. The plane pivots about its top edge (at z=0), so
        # the cut leans away from vertical going downward.
        self.wedge_plane_angle = wedge_plane_angle

        # Vertical distance between stacked floors (column + support height).
        # Used to lift the floor plates to the top of the columns; consumed by
        # FloorModel.story_height and by the examples that stack quarters.
        self.bay_height = bay_height

        # parabolas parameters
        self.height = height
        self.rise = rise
        self.static_h = height - rise
        self.column_head_lowest_height = -730

        # caches (invalidated lazily)
        self._oculus_pts = None
        self._q_poly = None
        self._c_poly = None
        self._axes = None
        self._boundary_parabolas = None
        self._construction_planes = None
        self._quad_planes = None
        self._construction_quads = None
        self._block_level_bottom = None
        self._block_level_top = None

        self.debug = []

        # on/off elements
        self.output_wedges = False

    @property
    def __data__(self) -> dict:
        return {
            "size_grid_x": self.size_grid_x,
            "size_grid_y": self.size_grid_y,
            "size_column_head": self.size_column_head,
            "size_column_head_chamfer": self.size_column_head_chamfer,
            "size_outer_ribs": self.size_outer_ribs,
            "size_inner_ribs": self.size_inner_ribs,
            "size_inner_beams": self.size_inner_beams,
            "size_wedge": self.size_wedge,
            "size_tsections": self.size_tsections,
            "height": self.height,
            "rise": self.rise,
            "size_oculus": self.size_oculus,
            "wedge_plane_angle": self.wedge_plane_angle,
            "bay_height": self.bay_height,
        }

    # The plate groups the guide produces, in the order a quarter is assembled.
    PLATE_GROUPS = ("outer_ribs", "inner_ribs", "inner_beams", "tsections", "beds", "oculus", "column_cutters")

    def plates(self) -> list:
        """Every :class:`compas_tf.plate.PlateElement` the guide produces, flattened.

        Each group is a lazy property, so this builds them all on first call.
        """
        plates = []
        for group in self.PLATE_GROUPS:
            value = getattr(self, group, None)
            if value is None:
                continue
            plates.extend(value if isinstance(value, (list, tuple)) else [value])
        return [plate for plate in plates if isinstance(plate, PlateElement)]

    def brep_meshes(self, variant=None) -> list:
        """The geometry of every plate the guide produces - what :meth:`get_brep` converts."""
        return [plate.placedgeometry for plate in self.plates()]

    @classmethod
    def __from_data__(cls, data: dict) -> "FloorGuide":
        return cls(**data)

    # ------------------------------------------------------------------ #
    #  Column grid
    # ------------------------------------------------------------------ #

    def corner_point_column(self, column_size=200):
        """Column base center in plan for one quarter (the grid corner).

        Mirrors the position the columns and supports are placed at: the
        bottom-left corner of the quarter grid, inset by half the column size.

        Parameters
        ----------
        column_size : float
            Column cross-section side length in mm.

        Returns
        -------
        :class:`compas.geometry.Point`
        """
        return Point(
            -(self.size_grid_x - column_size * 0.5),
            -(self.size_grid_y - column_size * 0.5),
            0,
        )

    # ------------------------------------------------------------------ #
    #  Floor plan geometry (2D)
    # ------------------------------------------------------------------ #

    @property
    def oculus_points(self):
        """Four points whose distance is sqrt(2) * oculus."""
        if self._oculus_pts is None:
            self._oculus_pts = [
                Point(0, -self.size_oculus_y, 0),
                Point(self.size_oculus_x, 0, 0),
                Point(0, self.size_oculus_y, 0),
                Point(-self.size_oculus_x, 0, 0),
            ]
        return self._oculus_pts

    @property
    def quarter_polygon(self):
        """The main polygon of the floor."""
        if self._q_poly is None:
            self._q_poly = Polygon(
                [
                    Point(-self.size_grid_x, -self.size_grid_y, 0),
                    Point(0, -self.size_grid_y, 0),
                    self.oculus_points[0],
                    self.oculus_points[3],
                    Point(-self.size_grid_x, 0, 0),
                ]
            )
        return self._q_poly
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

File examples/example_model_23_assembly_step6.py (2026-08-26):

"""Assembly step 6 - land the first quarter of the floor, with its steel and its dowels.

Fifth of the ``example_model_23_assembly_*`` series; see step 2 for how the
previews reach the docs.

The four columns are up (step 4) and propped (step 5), so the first piece of
floor can go on. A QUARTER is one of the four children of ``quarters_model`` in
``data/cantilevers_baked_model.json`` - 34 plates: 2 outer ribs, 2 inner ribs,
3 inner beams, 3 inner-beam wedge plates, 6 t-sections and 18 bed plates. It
arrives as one assembled unit and is lowered onto ONE column.

WHAT COMES WITH IT
------------------
- the QUARTER, ``quarter_model_0`` - 34 plates;
- the two COLUMN STEEL PLATES for that column. In the model these are
  :class:`compas_tf.connectors.ConnectorElement` (the top-level ``connectors``
  group, 8 of them, 2 per column). Each is a flat 485 x 30 x 250 mm steel plate
  let into a slot that runs right through the column head and on into the end of
  a rib: ``BACK = 220`` mm on the column side - the full width of the shaft -
  and ``FRONT = 265`` mm into the rib;
- the DOWELS that pin those plates. In the model these are
  :class:`compas_tf.connectors.DowelCylinderElement` (the top-level
  ``connector_cylinders`` group, 32 of them, 4 per steel plate), named
  ``cylinder_column_0/1`` and ``cylinder_rib_0/1`` after the side they are
  driven from. They are made by
  :meth:`compas_tf.connectors.ConnectorElement.cylinder_elements` off the same
  ``_dowel_grid`` that drilled the holes, so a dowel and its hole cannot drift.

DO NOT CONFUSE THEM with the OTHER cylinders in the file. The 32
:class:`compas_tf.connectors.ConnectorCylinderElement` under
``floor_model/connectors`` are the screws through the contact wedges, and they
belong to step 9. Ø 50 x 100 pins here; Ø 20 x 160 screws there.

The plates and the dowels are not matched by name. Each steel plate is given the
column and the quarter THE MODEL'S OWN CONTACTS say it touches, and each dowel
is placed in a plate by transforming its centre into that plate's local frame
and testing it against the box - so a dowel in the wrong quarter would come out
as a plate with three dowels, not as a clean four.

WHAT THERE IS NO PLATE ON
-------------------------
There is no head plate on top of a column. The head plates in this model are the
ones under the columns, on the Sherpa Power Bases of step 3, at ``z = 150``. Up
here the column ends in a CAPITEL that flares out of the 220 mm shaft, and the
ribs are seated straight onto its sawn faces - so the check below is not "how
big is the gap over the plate" but "do the rib faces and the capitel faces lie
on the same planes". They do, to 0.0000 mm, and not one of the 11 bearing faces
is horizontal: every one of them is raked about 9 degrees off vertical. The
quarter is not set down on a seat, it is dropped onto a taper.
"""

import math
import pathlib
from collections import defaultdict

import compas
from compas.colors import Color
from compas.geometry import Point
from compas.geometry import Vector
from compas_model.elements import Group
from compas_viewer import Viewer

from compas_tf.column import ColumnElement
from compas_tf.connectors import ConnectorElement
from compas_tf.model import TFModel
from compas_tf.support import SupportElement
from compas_tf.viewer import zoom_to
from compas_tf.writer import write_colored_obj

data_dir = pathlib.Path(__file__).parent.parent / "data"
assembly_dir = data_dir / "assembly"

STEP = "assembly_step6"

# Which of the four quarters goes on first. The other three are step 7.
QUARTER = 0

# One colour for every object - the black feature edges separate the parts.
STEEL = Color(0.72, 0.74, 0.76)
BLACK = Color(0.05, 0.05, 0.05)

# What is already standing is ghosted; what this step adds is solid.
GHOST = (0.72, 0.74, 0.76, 0.22)
COLUMN_OPACITY = 0.25  # the compas viewer's own way of saying the same thing

# ------------------------------------------------------------------ #
# The model, and the two ways of reaching into it.
#
# There are TWO groups called ``connectors`` in this file - the column steel
# plates at the top level, and the wedges plus their screws under
# ``floor_model``. So groups are walked by PATH from the root, never found by a
# bare name search, which would silently return whichever one comes first.
# ------------------------------------------------------------------ #

model: TFModel = compas.json_load(data_dir / "cantilevers_baked_model.json")


def group_node(*path):
    """The tree node of a group, addressed by its path of names from the root."""
    node = model.tree.root
    for name in path:
        node = next(child for child in node.children if isinstance(child.element, Group) and child.element.name == name)
    return node


def group_parts(node):
    """Every non-group element under a node."""
    return [child.element for child in node.descendants if not isinstance(child.element, Group)]


def contact_map():
    """``{id(element): [(other, contacts), ...]}`` - the model's own answer to what touches what."""
    table = defaultdict(list)
    for edge in model.graph.edges():
        contacts = model.graph.edge_attribute(edge, name="contacts")
        if not contacts:
            continue
        a = model.graph.node_element(edge[0])
        b = model.graph.node_element(edge[1])
        table[id(a)].append((b, contacts))
        table[id(b)].append((a, contacts))
    return table


touching = contact_map()

quarter_node = group_node("floor_model", "quarters_model", f"quarter_model_{QUARTER}")
quarter_parts = group_parts(quarter_node)
quarter_ids = {id(element) for element in quarter_parts}

plates = sorted(group_parts(group_node("connectors")), key=lambda element: element.name)
dowels = group_parts(group_node("connector_cylinders"))

columns = sorted((element for element in model.elements() if isinstance(element, ColumnElement)), key=lambda element: element.name)
supports = sorted((element for element in model.elements() if isinstance(element, SupportElement)), key=lambda element: element.name)

print(f"quarter_model_{QUARTER}: {len(quarter_parts)} plates")
for child in quarter_node.children:
    if isinstance(child.element, Group):
        print(f"  {child.element.name:24s} {len(group_parts(child)):3d}")

# ------------------------------------------------------------------ #
# Which column does this quarter go on? The model is asked, not told.
#
# Every contact between one of the quarter's plates and a column is counted. A
# quarter that belonged to another column would show up as contacts spread over
# two of them, or as none at all.
# ------------------------------------------------------------------ #

on_column = defaultdict(lambda: [0, 0.0])
for plate in quarter_parts:
    for other, contacts in touching[id(plate)]:
        if isinstance(other, ColumnElement):
            on_column[other.name][0] += len(contacts)
            on_column[other.name][1] += sum(contact.polygon.area for contact in contacts)
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

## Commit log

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2025-12-05 WIP floor diagonal ribs missing with step cut
2026-01-14 Connection details
    [all_elements.obj, column_heads.obj, columns.obj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]
2026-01-15 WIP joints
    [model_export.obj]
2026-01-15 Add modifiers, mesh winding correction wip
    [model_export.obj]
2026-01-15 Modifiers main ones are working
    [model_export.obj]
2026-01-15 Damn mesh booleans fails of cgal...
    [model_export.obj]
2026-01-16 LINT: Safe import cleanup preserving geometry computation chain
    - Reorder imports (stdlib first, then alphabetical)
    - Remove unused imports (Polygon, PlaneIntersect from column_head.py)
    - CRITICAL: Preserve rib_parabolas access in floor_builder.end_planes
    (triggers boundary_parabolas which computes head_h as side effect)
    - Add noqa comments to prevent future linters from breaking geometry
2026-01-16 quarter floor offset axes
    [model_export.obj]
2026-01-16 quarter floor rib ends are cut by 0 1 1 2 and front ends by 0 0 2 2
    [model_export.obj]
2026-01-16 screws and dowels
    [model_export.obj]
2026-01-16 ADD oculus
    [model_export.obj]
2026-01-18 Solve oculus
    [model_export.obj]
2026-01-18 Add oculus connections and quarter connection following the boundary polylines instead of central axes
    [model_export.obj]
2026-01-18 Add quarter connector strips
    [model_export.obj]
2026-01-18 Fix one screw
    [model_export.obj]
2026-01-18 Fix one strip locaiton
    [model_export.obj]
2026-01-19 Add quarter floor rotation
    [model_export.obj]
2026-01-19 Oculus convert to polylines and fix adjacency
    [model_export.obj]
2026-01-19 Milestone: Fix connector adjacency and add plate elements
    [model_export.obj]
2026-01-19 inner surface subdivision
    [model_export.obj]
2026-01-21 MILESTONE: strips and reciprocal offset finished
    [model_export.obj]
2026-01-21 Fix plate orientation
    [model_export.obj]
2026-01-21 model hierarchy including rhino
    [model_export.obj]
2026-02-02 Split rib in two
    [hilti.3dm]
2026-02-03 WIP quarter to quarter connection
    [hilti.3dm]
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2026-05-08 Milestone quarter done, prepared cutter for the column
    [floorguide.obj]
2026-05-09 milestone floor with major elements together
    [ScrewHeads.obj, floor_tower_0.obj, schoring_head_custom.obj]
2026-05-26 Wedges on inner beams
    [wedge.obj, wedge.stp, wedge_boolean.obj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]
2026-06-16 column heads
    [all_elements.obj, column_0.obj, column_1.obj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]
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2026-06-19 manifold usage
    [floor_model_2026-06-19.obj]
2026-06-20 Remove FloorBuilder; FloorGuide single source + dead-code/data cleanup
    - FloorGuide is the single parametric floor source; FloorModel(guide=...).
    Removed FloorBuilder and the element family on it (quarter_floor, column_head,
    oculus), FloorModel.add_oculus(), and examples/model.py build_model().
    - corner_point_column() moved to FloorGuide; example_2 dumps floorguide.json.
    - Removed unused modules (prop, joint_hilti, joint_screw, joint_strip) and dead
    geometry code (PlaneIntersect, LineOffset, and unused PolylineOffset/Cut/Loft methods).
    - Migrated all examples to the guide API; pruned imports (ruff clean).
    - Deleted orphaned/broken data artifacts (FloorBuilder session.json, stale model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
    [ScrewHeads.obj, column_0.obj, column_1.obj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]
2026-06-20 Manifold-only booleans; fix example_1/example_7; gitignore dated OBJ exports
    - All mesh booleans now use compas_manifold exclusively (difference, union,
    chain); removed the compas_cgal fallback and dependency. Direct cgal calls in
    column.py (capitel union) and floor_model.py (union_cutter_meshes) switched to
    manifold. compas_cgal dropped from requirements.txt.
    - compute_contacts_inner_beams no longer calls precompute_boolean_modifiers
    internally (the caller does it once) — removes a duplicate boolean pass.
    - example_2 top docstring made raw (fixes the \c SyntaxWarning).
    - Fix example_1_floorguide and example_7_assembly_quarter: FloorGuide rename
    wedges_column -> wedges_inner_beam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
    [floor_model_2026-06-19.obj]
2026-06-22 MILESTONE: model branching
    [example_2_floor_model.obj, example_model_7_contacts_columns.obj, floor_model.obj]
2026-06-23 EXMAPLES fab models
    [floor_model.obj]
2026-06-24 column fab wip
    [cantilevers_model.obj, floor_model.obj]
2026-07-02 compas_occt step export and polygonal mesh reconstruction fix
    [OuterRibConnector.obj, OuterRibConnector_Result.obj, OuterRibConnector_cut0.obj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]
2026-07-02 Connectors withing quarters and projected bolts
    [cantilevers_model.obj, floor_model.obj]
2026-08-02 Add Custom_Cutting_Connectors export; refresh cantilevers + OuterRibConnector data
    Data-only update: the new Custom_Cutting_Connectors folder ships the Mill_6mm /
    Ramp_2mm toolpath OBJs and the geometry STEP that the compas_cnc connector fab
    examples read, and the cantilevers and OuterRibConnector exports are regenerated
    from the current model.
    [Mill_6mm.obj, OuterRibConnector.obj, OuterRibConnector_Result.obj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]
2026-08-09 Baked model + STEP export, PyPI trusted publishing, faster mesh->Brep
    Packaging
    - release.yml publishes via PyPI trusted publishing (OIDC): new `publish`
    job with `environment: pypi` and `id-token: write`, using
    pypa/gh-action-pypi-publish. compas-actions.publish is kept for the
    GitHub release only (`publish_to_pypi: false`) - it uploads with twine
    and a token, so it cannot use a trusted publisher.
    - Move the compas_viewer fork out of requirements.txt into
    requirements-viewer.txt. pyproject feeds requirements.txt into the
    package metadata, and PyPI rejects any distribution whose Requires-Dist
    contains a direct URL, so the git dependency made the upload fail.
    compas_tf imports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
    [cantilevers_model.obj, floor_model.obj]
2026-08-09 Vendor the four Model methods into TFModel; contacts in example 19
    compas_tf depended on FOUR compas_model methods that are not in any
    release - duplicate, merge, compute_contacts_between_groups and
    find_group_with_name. They exist only on an unmerged branch, which is
    installed here as an editable checkout of C:\brg\compas_model, so the
    dependency was invisible locally and would have broken for anyone
    installing compas_tf from PyPI.
    Verified by reading compas_model/models/model.py out of the published
    0.9.3 wheel: all four are absent (compute_contacts is the only contact
    method there). Every name the vendored code needs - Element, Group,
    Contact, Material, ElementNode, ElementBVH, Model.add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
2026-08-09 Vendor Model as base_model, move every example to TFModel, regenerate data
    compas_tf no longer inherits from compas_model's Model.
    - src/compas_tf/base_model.py is a verbatim copy of
    compas_model/models/model.py, with `Model` renamed to `BaseModel` and
    its relative imports made absolute. TFModel subclasses it, so the four
    methods that exist only on an unmerged compas_model branch - duplicate,
    merge, compute_contacts_between_groups, find_group_with_name - come
    from inside compas_tf. Everything base_model imports FROM compas_model
    (Element, Group, Contact, Material, Modifier, KDTree, ElementTree,
    ElementNode, InteractionGraph, the BVH nodes) does ship in 0.9.3.
    Kept verbatim r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
2026-08-09 Ship the OBJ meshes as package data
    SupportElement.DATA_DIR and OuterRibConnectorElement.OBJ_DIR both pointed
    at the repository's data/ folder via __file__.parent.parent.parent, which
    only resolves inside a checkout. Installed from PyPI it became
    <site-packages>/../../data, so deserializing ANY model containing a
    support died in SupportElement.__init__ with
    FileNotFoundError: .venv\Lib\data\column_base_power_base_sherpa_...obj
    Both meshes are read at construction time, so this hit every consumer of
    a published model - not an edge case. Found by building the standalone
    example repo against compas_tf 0.1.2 from PyPI, which is exactly the path
    the repo's own examples never exercise.
    The OB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
    [OuterRibConnector.obj, OuterRibConnector_Result.obj, OuterRibConnector_cut0.obj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]
2026-08-10 Ship scene objects; examples use the stock compas_viewer API; drop the fork
    compas_tf now registers its own viewer scene objects through the standard
    compas plugin mechanism (__all_plugins__ -> compas_tf.scene), the same way
    compas_occt does for OCCBrep. An element draws itself, so an example is
    just:
    from compas_viewer import Viewer
    viewer = Viewer()
    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
2026-08-10 Add Brep-face contact detection
    Contacts were computed on element.modelgeometry - the triangles a boolean
    leaves behind - so one physical interface came back as several contact
    polygons, and area went missing: on one of the 8 identical column/rib joints
    the mesh route returns 50344 mm2 instead of 62632, invisibly, because that
    interface is already in pieces.
    compas_tf.contacts runs the search on Brep faces instead. mesh_to_brep merges
    the boolean triangles back into the modelled faces and a Brep face carries its
    hole loops, so the same joint is 1 contact of the full area.
    The face pairs are prefiltered on opposite normals and boundary AABBs rather
    than by Brep.overlap: overlap() works on O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
2026-08-10 Build the plate loft lazily, not on load
    PlateElement.__init__ lofted its mesh from the top/bottom polylines for every
    plate it constructed. compute_elementgeometry is the only reader of that mesh
    and it is @baked, so a baked plate returns its stored geometry and never looks
    at the loft - all 145 plates built one and threw it away on every load.
    compas.json_load of the cantilevers model: 3.3 s -> 0.60 s. For scale, a raw
    json.loads of the same 3.9 MB file is 0.09 s, so the remaining overhead is
    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
2026-08-10 Add group extraction, example 21 and the reader docs
    find_groups_with_names lifts named groups out as a standalone model.
    Extracting both a column group and the quarter it carries in ONE call is what
    keeps the contacts between them; done separately and merged, every contact
    stays inside its own group and the joint connecting them is lost.
    neighbors=True reaches one step out for the elements that touch the bay from
    outside it - the fasteners live in their own top-level groups, so without it a
    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
2026-08-10 Move the docs from Sphinx to mkdocs-material
    Same template as compas_cgal: mkdocs-material with mkdocstrings for the API,
    mike for versioning, and the pymdownx snippet syntax so every example page pulls
    in the real file from examples/ rather than a copy that can drift.
    - mkdocs.yml and requirements-docs.txt, ported from compas_cgal.
    - docs/*.rst -> markdown. index, installation, tutorial, license (a snippet of
    LICENSE), changelog (a snippet of CHANGELOG.md), and the six example pages.
    - docs/api/compas_tf.<module>.md, one '::: compas_tf.<module>' per module, in
    place of the autosummary listing.
    - Screenshots on the three reader pages. 19 and 20 are the same building from
    the two files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
2026-08-10 Find the fasteners the graph cannot see
    neighbors= was a graph walk only, and the contact search skips the fasteners -
    a faceted shaft touches its own hole once per facet, 74% of the contacts for no
    structural information - so 64 of the 237 elements have no edge for a walk to
    follow. A bay came out with its connectors and without the 32 dowels and 32
    cylinders that bolt them on.
    Geometry is the only signal left for those, so an element with no interactions
    at all is now included when its bounding box lands inside the bay. Restricted to
    the unlinked: on elements the graph does describe, a box test is far too loose -
    tried on all of them it dragged in 34 unrelated plates, one diagonal rib's b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
2026-08-10 Document the requirements and a from-scratch install
    The installation page said what to type but not what any of it pulls in, and it
    was wrong about the Python floor: it blamed the Brep kernel's wheels, but
    compas_occt ships cp39-cp312, and it is shapely that needs 3.10. It also missed
    the thing most likely to bite - there is no cp313 wheel, so 3.13 tries to build
    the kernel from source and fails.
    Now: a table of the five runtime dependencies and what each is for, the real
    Python range, clone-to-verified steps with both uv and stock venv, and the
    `uv pip` gotcha (a uv venv has no pip of its own, so a bare `pip install` lands
    in whatever environment is first on PATH). Every command and every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
    [example_2_floor_model.obj, example_model_7_contacts_columns.obj]
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2026-08-10 Narrow the bay to its own hardware, and show it
    A bay is a column, the cantilever it carries and what bolts the two
    together. The wedges and their bolts are inner-beam hardware and the
    outer-rib connectors join one quarter to the next, so naming only
    ConnectorElement and DowelCylinderElement takes the bay from 64 elements
    to 46. The docs page gets the viewer screenshot of the result, and the
    reader examples lose the timing scaffolding the documentation replaced.
    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
2026-08-10 Trim examples 18-22, frame the camera, and give the counts
    Comments: dropped the section banners and the paragraphs restating what the
    line below already says, kept the facts that cost something to rediscover - why
    contacts run on Breps, why the fasteners are skipped, why STEP needs the
    sidecar, why neighbors takes types. Example 18 loses its perf_counter
    scaffolding; it writes four files and now just says so.
    Camera: on a model in millimetres the viewer starts at [-10, -10, 10] with a far
    plane of 1000, so a 6015 mm building is entirely clipped until you press F.
    compas_viewer's zoom_selected cannot be called for you - it reads the scene
    objects' bounding boxes, which do not exist until th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
2026-08-10 Pin the docs workflow to Python 3.12
    python-version: 3.x resolved to 3.14.6, and pyproject now caps at <3.13 because
    compas_occt and compas_manifold have no cp313 wheels - so `pip install .` failed
    before mkdocs ever ran. build.yml and release.yml already pin 3.10.
    Claude-Session: https://claude.ai/code/session_01K3tR8rCe4Ljc1KN49xo6Af
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2026-08-10 Correct the Python range: no upper bound
    compas_occt and compas_manifold ship a cp312-abi3 wheel, built against the
    stable ABI, so it installs on every CPython from 3.12 on - I had read the
    python tag and missed the abi tag, and capped requires-python at <3.13 on that
    mistake. That cap is what broke the docs workflow.
    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
2026-08-10 Drop Python 3.9 from the release build matrix
    requires-python is >=3.10, so the 3.9 leg failed with "requires a different
    Python", and both github-release and publish need the build - v0.1.11 tagged
    with nothing published. build.yml already runs 3.10 only.
    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
2026-08-10 Split the two uv workflows on the installation page
    They were mixed together, which is what makes uv confusing. Consuming the
    package is uv init / uv add / uv run - uv owns the environment, nothing is
    activated. Working on the repository is uv venv / source activate / uv pip,
    because you want an environment you stay inside.
    Every command on the page was run: uv venv prints the activate line itself,
    `which pip` inside a uv venv genuinely finds nothing, `uv pip install` lands in
    the activated environment, and uv init / uv add / uv run resolve compas_tf.
    That last one also settles "verified up to 3.14" properly: uv init defaults the
    project to requires-python >=3.14, uv add installed compas_t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
2026-08-19 column docs and example refinement
    [column_0_fab.obj, column_0_fab.stp, column_0_preview.obj]
2026-08-20 qunatities with 3D viewer
    [beds_0_fab.obj, beds_0_fab.stp, beds_0_preview.obj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]
2026-08-25 Add assembly documentation pager with survey and column prep steps
    A new `docs/assembly.md` sits after the part list: one section per assembly
    step, each a title, a 3D viewer and a description, no tables. Two steps so far,
    written by `examples/example_model_23_assembly_step*.py`.
    Step 1 is the survey - a total station on the centre of the bay shooting the 4
    bolt holes and 4 plate corners of every support, 32 points. Step 2 lays the
    columns on their side with the head plate screwed into a pocket in the end.
    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
    [assembly_step1_preview.obj, assembly_step2_preview.obj, total_station_es105.obj]
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2026-08-25 WIP: assembly steps, jig reconstruction, and compas_occt 0.1.19
    Checkpoint so this branch can be picked up on another machine. The branch had
    never been pushed and ~33 files were untracked, including assembly steps 3-9,
    assembly_shoring.py and the jig photo the docs page embeds - none of it would
    have travelled.
    Full notes in .claude/plans/session_handoff.md; the migration plan and every
    measurement behind it are in .claude/plans/brep_migration.md.
    compas_occt v0.1.19 is released (PyPI, 4 wheels + sdist) with two fixes found
    here: flat polygons were built as fitted surfaces rather than planar faces, and
    boolean results were sewn into loose shells so .solids came back empty on any
    cut that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
    [assembly_step1_preview.obj, assembly_step2_preview.obj, assembly_step3_preview.obj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]
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2026-09-07 session: write a TFModel to a session .pb, one tagged Element per element
    Every element becomes ONE session_py.Element carrying its mesh plus a type tag
    (Plate / Column / Solid), so a consumer reads what a thing IS off element_type
    rather than guessing from its name. Plates carry their bottom+top outline pair
    and columns their axis+section, which is what wood rebuilds a plate from. The
    group hierarchy is mirrored into the session tree.
    This replaces the STEP route, which re-matched solids back to names by
    bounding-box centre and emitted untyped meshes - so the plate's bottom/top
    pair, which the model HAS, never reached the consumer.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
